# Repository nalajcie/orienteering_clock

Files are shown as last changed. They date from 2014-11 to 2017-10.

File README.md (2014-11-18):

# Introduction
This is *work-in-progress* project to build orienteering clock, currently in prototyping phase. I will put more information here when it will be completed.

# Contents
 * `src/` - Arduino prototype source for driving multiplexed LED display and time counting. It's best to link this folder to your Arduino projects folder:
  
  ```
    in Windows:
    > mklink /D c:\Users\$USER\Documents\Arduino\orienteering_clock c:\proj\orienteering_clock\src

    in Linux:
    $ ln -s src /home/$USER/sketchbook/orienteering_clock
  ```
 
 * `schematics/` - EAGLE and PDF schematics of prototype parts. It's best to link this folder to your Eagle library:

  ```
    in Windows:
    > mklink /D c:\Users\$USER\Documents\eagle\orienteering-clock C:\proj\orienteering_clock\schematics

    in Linux:
    $ ln -s schematics /home/$USER/eagle/orienteering-clock

  ```

 * `doc/` - documentation of parts, etc.

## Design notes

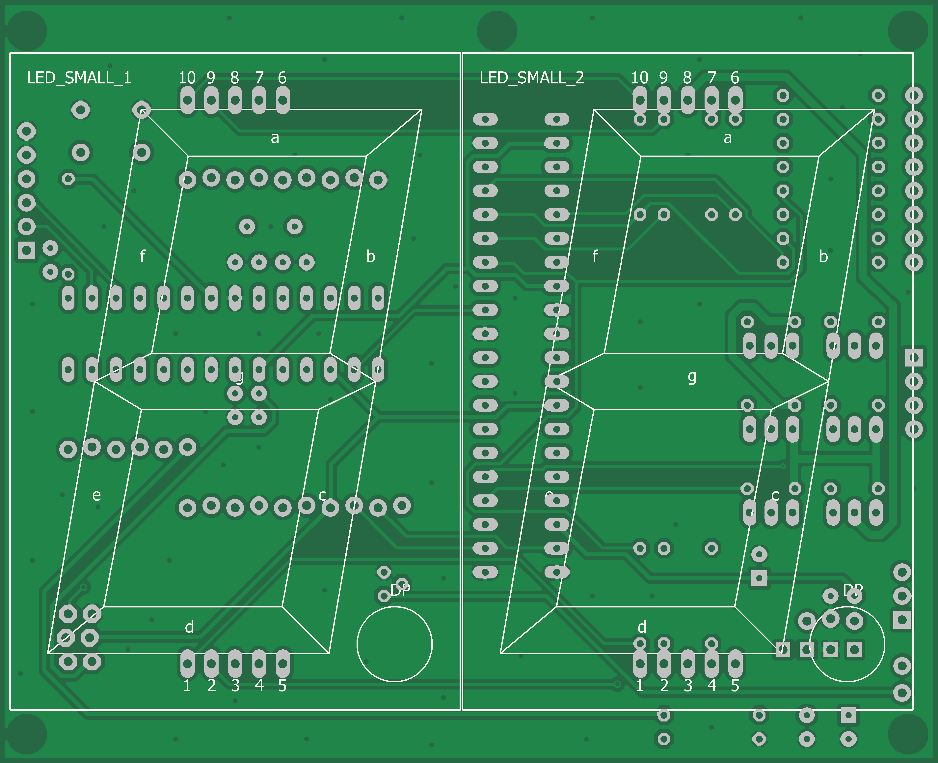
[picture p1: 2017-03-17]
schematics/eagleUp/eagleUp_orienteering_clock_rev2_board_bottom.png

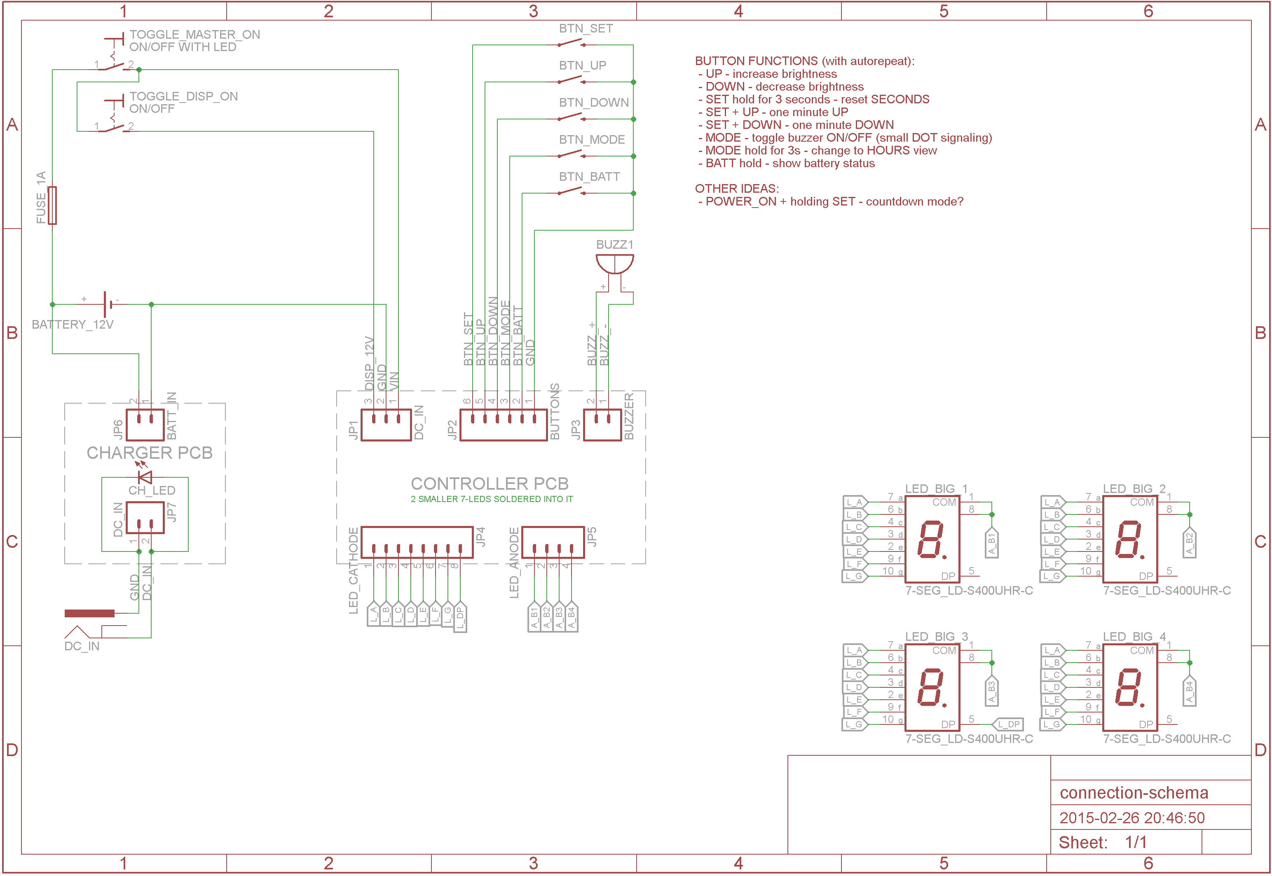
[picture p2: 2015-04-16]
schematics/pdf/connection-schema.sch.png

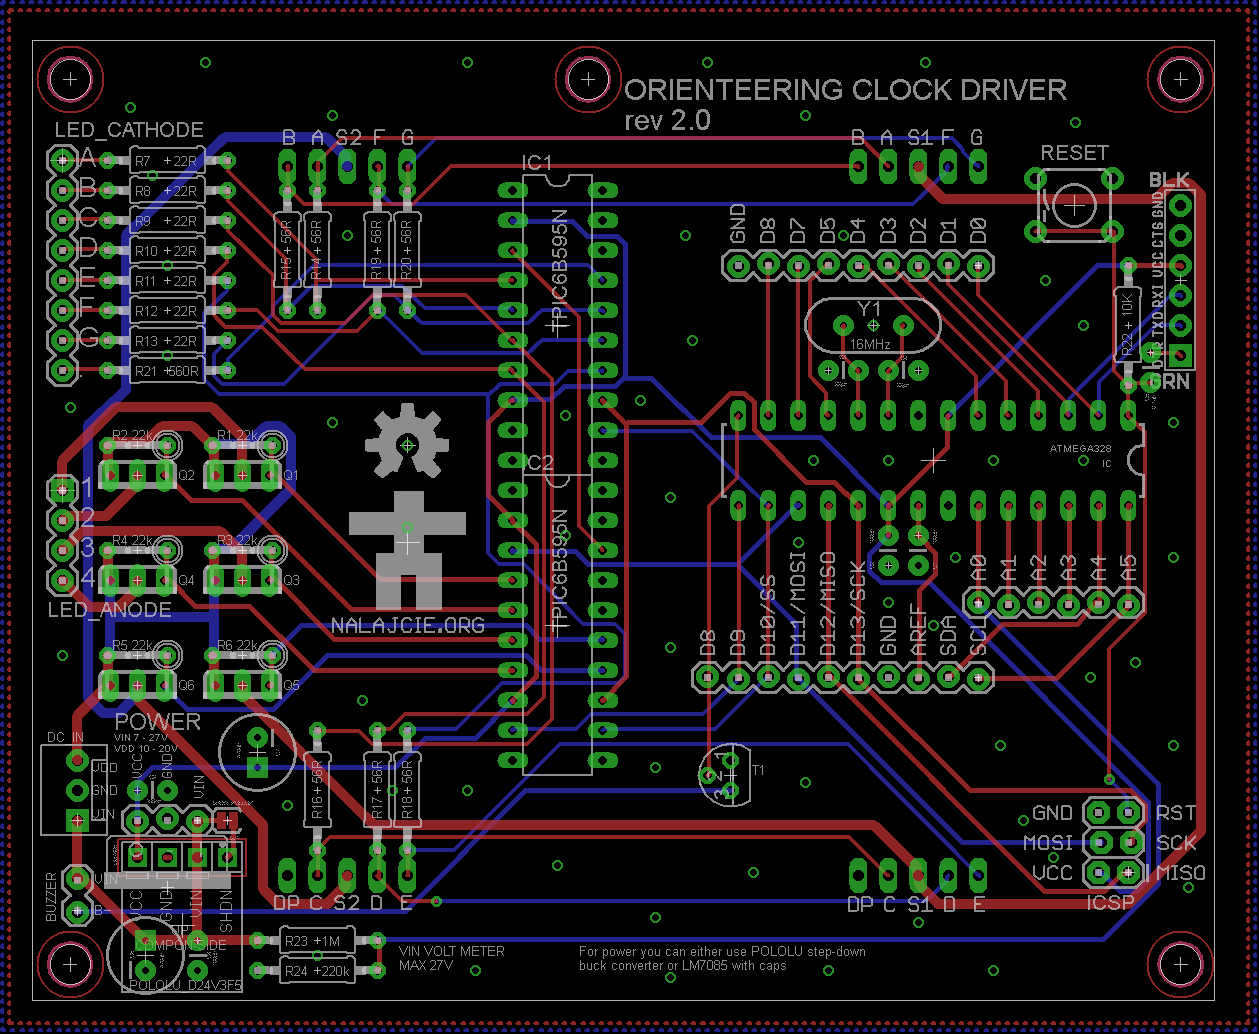
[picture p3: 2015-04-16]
schematics/pdf/orienteering_clock_rev2.brd.png

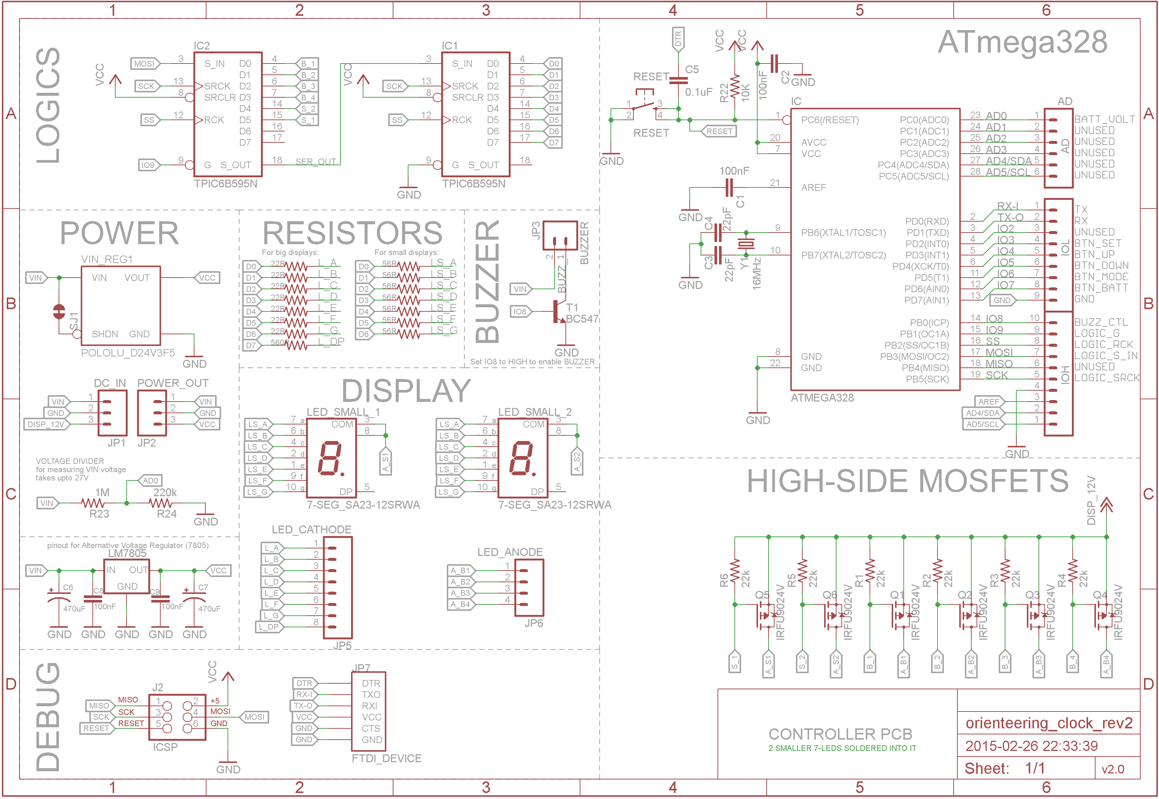
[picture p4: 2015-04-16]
schematics/pdf/orienteering_clock_rev2.sch.png

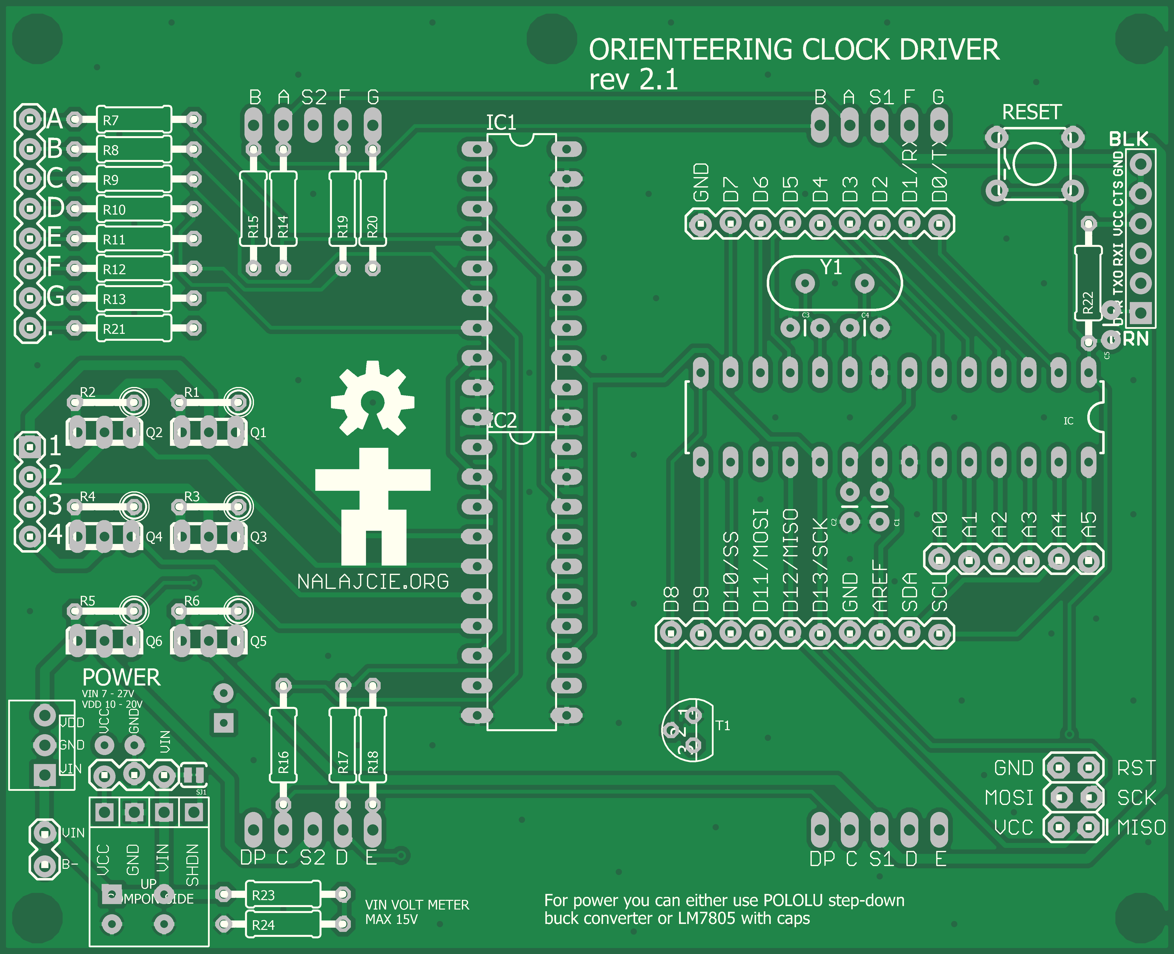
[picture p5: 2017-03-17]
schematics/eagleUp/eagleUp_orienteering_clock_rev2_board_top.png

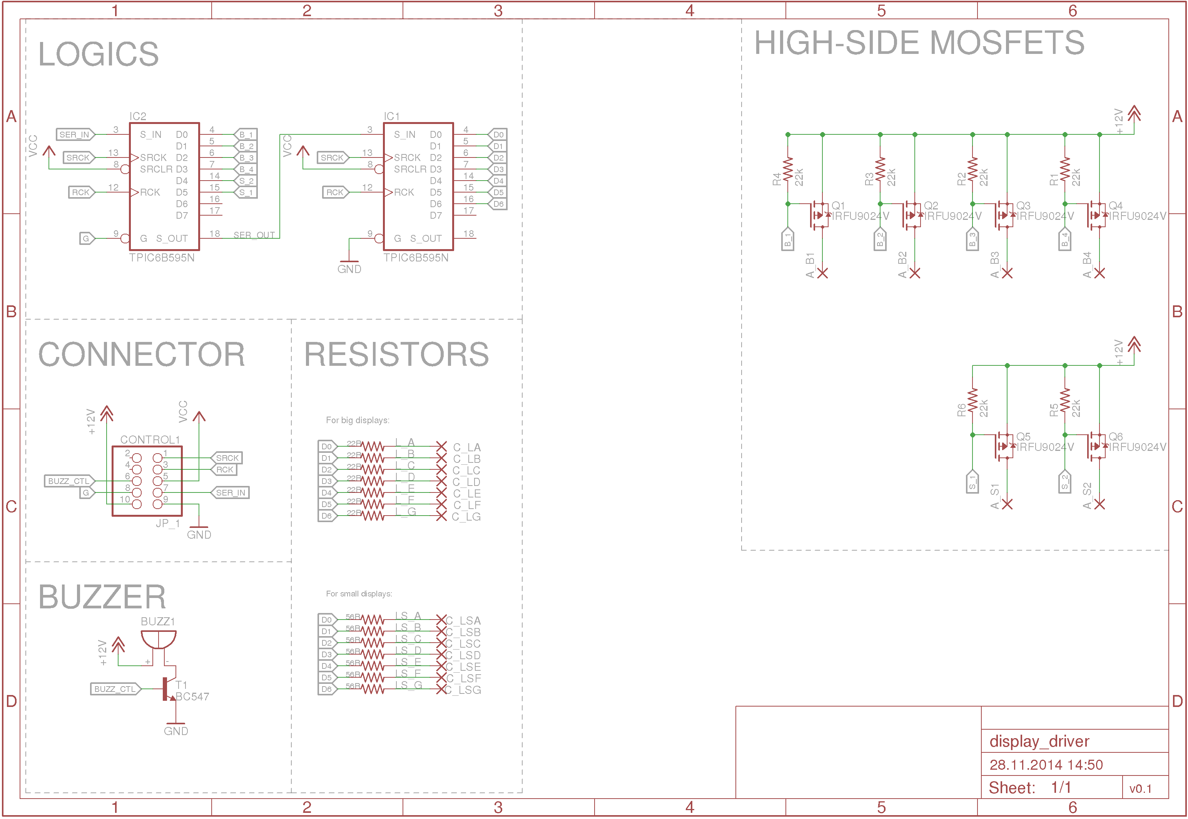
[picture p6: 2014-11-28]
schematics/v1.0/display_driver_schematics.png

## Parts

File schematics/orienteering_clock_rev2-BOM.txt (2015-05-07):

Partlist exported from C:/proj/orienteering_clock/schematics/orienteering_clock_rev2.sch at 2015-04-16 19:34:28

Part        Value             Device                   Package                           Description                                                          
AD          AD                M06SIP_LOCK              1X06-SIP_LOCK                     Header 6                                                             
C1          100nF             CAPPTH                   CAP-PTH-SMALL                     Capacitor                                                            
C2          100nF             CAPPTH                   CAP-PTH-SMALL                     Capacitor                                                            
C3          22pF              CAPPTH                   CAP-PTH-SMALL                     Capacitor                                                            
C4          22pF              CAPPTH                   CAP-PTH-SMALL                     Capacitor                                                            
C5          0.1uF             CAPPTH                   CAP-PTH-SMALL                     Capacitor                                                            
C6          470uF             CAP_POLPTH1              CPOL-RADIAL-100UF-25V             Capacitor Polarized                                                  
C7          470uF             CAP_POLPTH1              CPOL-RADIAL-100UF-25V             Capacitor Polarized                                                  
C8          100nF             CAPPTH                   CAP-PTH-SMALL                     Capacitor                                                            
C9          100nF             CAPPTH                   CAP-PTH-SMALL                     Capacitor                                                            
IC          ATMEGA328         ATMEGA328P_PDIP          DIL28-3                           uC used in the Arduino                                               
IC1         TPIC6B595N        TPIC6B595N               DIL20                             8-bit SHIFT REGISTER, output latch                                   
IC2         TPIC6B595N        TPIC6B595N               DIL20                             8-bit SHIFT REGISTER, output latch                                   
IOH         M10LOCK           M10LOCK                  1X10_LOCK                         Header 10                                                            
IOL         M09LOCK           M09LOCK                  1X09_LOCK                         Header 9                                                             
J2          ICSP              AVR_SPI_PRG_62X3_LOCK    2X3_LOCK                          AVR ISP 6 Pin                                                        
JP1         DC_IN             M03POLAR                 MOLEX-1X3                         Header 3                                                             
JP2         POWER_OUT         M03LOCK                  1X03_LOCK                         Header 3                                                             
JP3         BUZZER            M02LOCK                  1X02_LOCK                         Standard 2-pin 0.1" header. Use with                                 
JP5         LED_CATHODE       M08                      1X08_ROUND                        Header 8                                                             
JP6         LED_ANODE         M04PTH                   1X04                              Header 4                                                             
JP7         FTDI_DEVICE       FTDI_DEVICE              FTDI_DEVICE_SIDE                  Connector which mates to FTDI basic or FTDI cable.                   
LED_SMALL_1 7-SEG_SA23-12SRWA 7-SEG_SA23-12SRWA        SA23-12SRWA                       Kingbright 14.2mm (0.56 INCH) SINGLE DIGIT NUMERIC DUISPLAY          
LED_SMALL_2 7-SEG_SA23-12SRWA 7-SEG_SA23-12SRWA        SA23-12SRWA                       Kingbright 14.2mm (0.56 INCH) SINGLE DIGIT NUMERIC DUISPLAY          
LM7805                        78XXS                    78XXS                             VOLTAGE REGULATOR - NO DRILL                                         
Q1          IRFU9024V         IRFU9024V                TO251AA-V                         P-CHANNEL MOSFET                                                     
Q2          IRFU9024V         IRFU9024V                TO251AA-V                         P-CHANNEL MOSFET                                                     
Q3          IRFU9024V         IRFU9024V                TO251AA-V                         P-CHANNEL MOSFET                                                     
Q4          IRFU9024V         IRFU9024V                TO251AA-V                         P-CHANNEL MOSFET                                                     
Q5          IRFU9024V         IRFU9024V                TO251AA-V                         P-CHANNEL MOSFET                                                     
Q6          IRFU9024V         IRFU9024V                TO251AA-V                         P-CHANNEL MOSFET                                                     
R1          22k               R-US_0207/5V             0207/5V                           RESISTOR, American symbol                                            
R2          22k               R-US_0207/5V             0207/5V                           RESISTOR, American symbol                                            
R3          22k               R-US_0207/5V             0207/5V                           RESISTOR, American symbol                                            
R4          22k               R-US_0207/5V             0207/5V                           RESISTOR, American symbol                                            
R5          22k               R-US_0207/5V             0207/5V                           RESISTOR, American symbol                                            
R6          22k               R-US_0207/5V             0207/5V                           RESISTOR, American symbol                                            
R7          22R               R-US_0207/10             0207/10                           RESISTOR, American symbol                                            
R8          22R               R-US_0207/10             0207/10                           RESISTOR, American symbol                                            
R9          22R               R-US_0207/10             0207/10                           RESISTOR, American symbol                                            
R10         22R               R-US_0207/10             0207/10                           RESISTOR, American symbol                                            
R11         22R               R-US_0207/10             0207/10                           RESISTOR, American symbol                                            
R12         22R               R-US_0207/10             0207/10                           RESISTOR, American symbol                                            
R13         22R               R-US_0207/10             0207/10                           RESISTOR, American symbol                                            
R14         56R               R-US_0207/10             0207/10                           RESISTOR, American symbol                                            
R15         56R               R-US_0207/10             0207/10                           RESISTOR, American symbol                                            
R16         56R               R-US_0207/10             0207/10                           RESISTOR, American symbol                                            
R17         56R               R-US_0207/10             0207/10                           RESISTOR, American symbol                                            
R18         56R               R-US_0207/10             0207/10                           RESISTOR, American symbol                                            
R19         56R               R-US_0207/10             0207/10                           RESISTOR, American symbol                                            
R20         56R               R-US_0207/10             0207/10                           RESISTOR, American symbol                                            
R21         560R              R-US_0207/10             0207/10                           RESISTOR, American symbol                                            
R22         10K               R-US_0207/10             0207/10                           RESISTOR, American symbol                                            
R23         1M                R-US_0207/10             0207/10                           RESISTOR, American symbol                                            
R24         220k              R-US_0207/10             0207/10                           RESISTOR, American symbol                                            
RESET       RESET             TAC_SWITCHPTH            TACTILE-PTH                       Momentary Switch                                                     
SJ1         SHDN_PULLUP       JUMPER-PAD-2-NC_BY_TRACE PAD-JUMPER-2-NC_BY_TRACE_YES_SILK                                                                      
T1          BC547             BC547                    TO92                              NPN TRANSISTOR                                                       
VIN_REG1    POLOLU_D24V3F5    POLOLU_D24V3F5-HC        POLOLU_D24V3F_HC                  Pololu Step Down Voltage Regulators Series D24V3F_ (300 mA)0.4"x0.5" 
Y1          16MHz             CRYSTALHC49US            HC49US                            Various standard crystals. Proven footprints.

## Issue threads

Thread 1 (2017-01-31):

Use old mobile display (resources)

Symbian9, 2017-01-31:
Here some usefull resources for using old mobile displays with Arduino:
* http://andybrown.me.uk/downloads/
  * https://github.com/andysworkshop/xmemtft

nalajcie, 2017-01-31:
We don't want to use old mobile displays for this kind of clock (they are waaay too small).

Currently we're using quite large 7-segment led display (single digit is 90x120mm).

I'll try to post more detailed instructions regarding build in the future, for now the finished clock looks like that:
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

Closed 2017-01-31.

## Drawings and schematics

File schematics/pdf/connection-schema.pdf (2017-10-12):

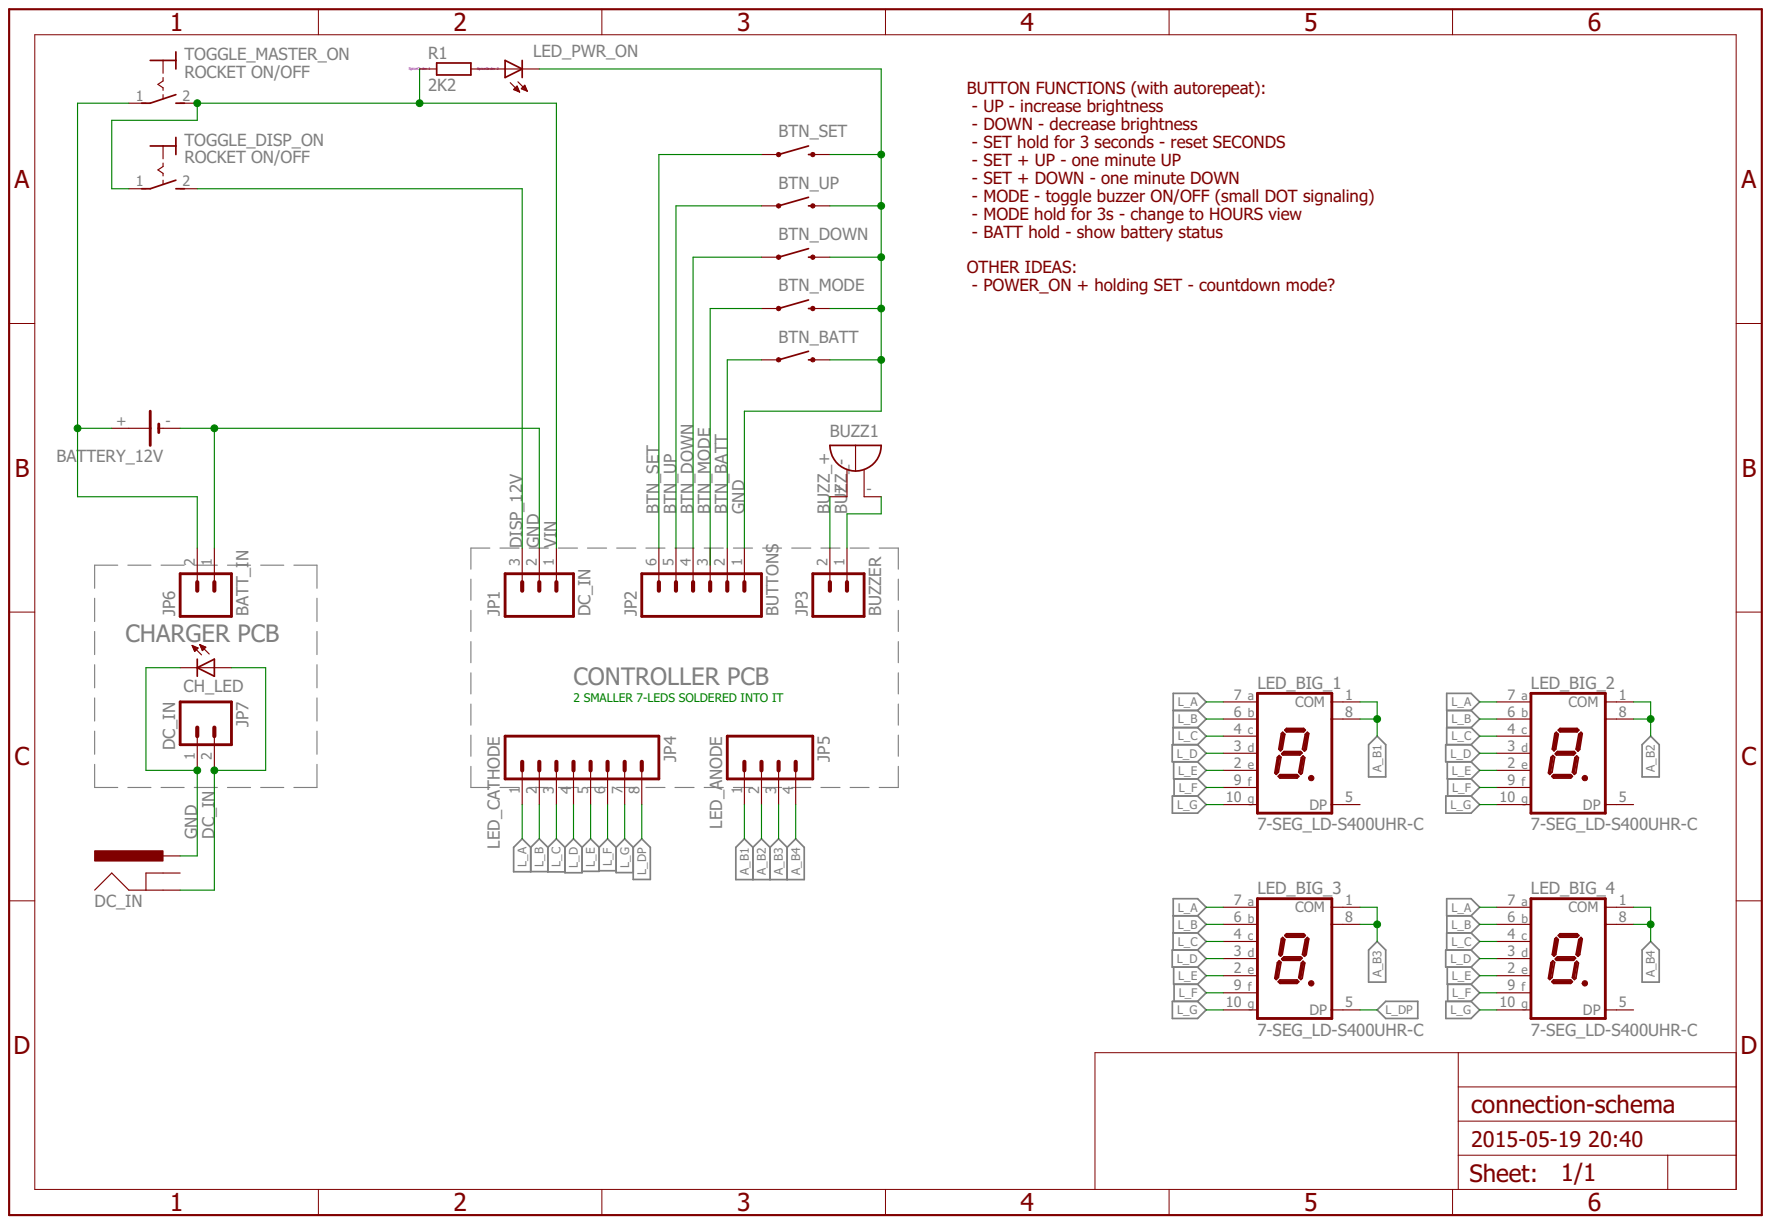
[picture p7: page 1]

BUTTON FUNCTIONS (with autorepeat): - UP - increase brightness

- DOWN - decrease brightness
- SET hold for 3 seconds - reset SECONDS
- SET + UP - one minute UP
- SET + DOWN - one minute DOWN
- MODE - toggle buzzer ON/OFF (small DOT signaling)
- MODE hold for 3s - change to HOURS view
- BATT hold - show battery status OTHER IDEAS: - POWER_ON + holding SET - countdown mode?

2 SMALLER 7-LEDS SOLDERED INTO IT

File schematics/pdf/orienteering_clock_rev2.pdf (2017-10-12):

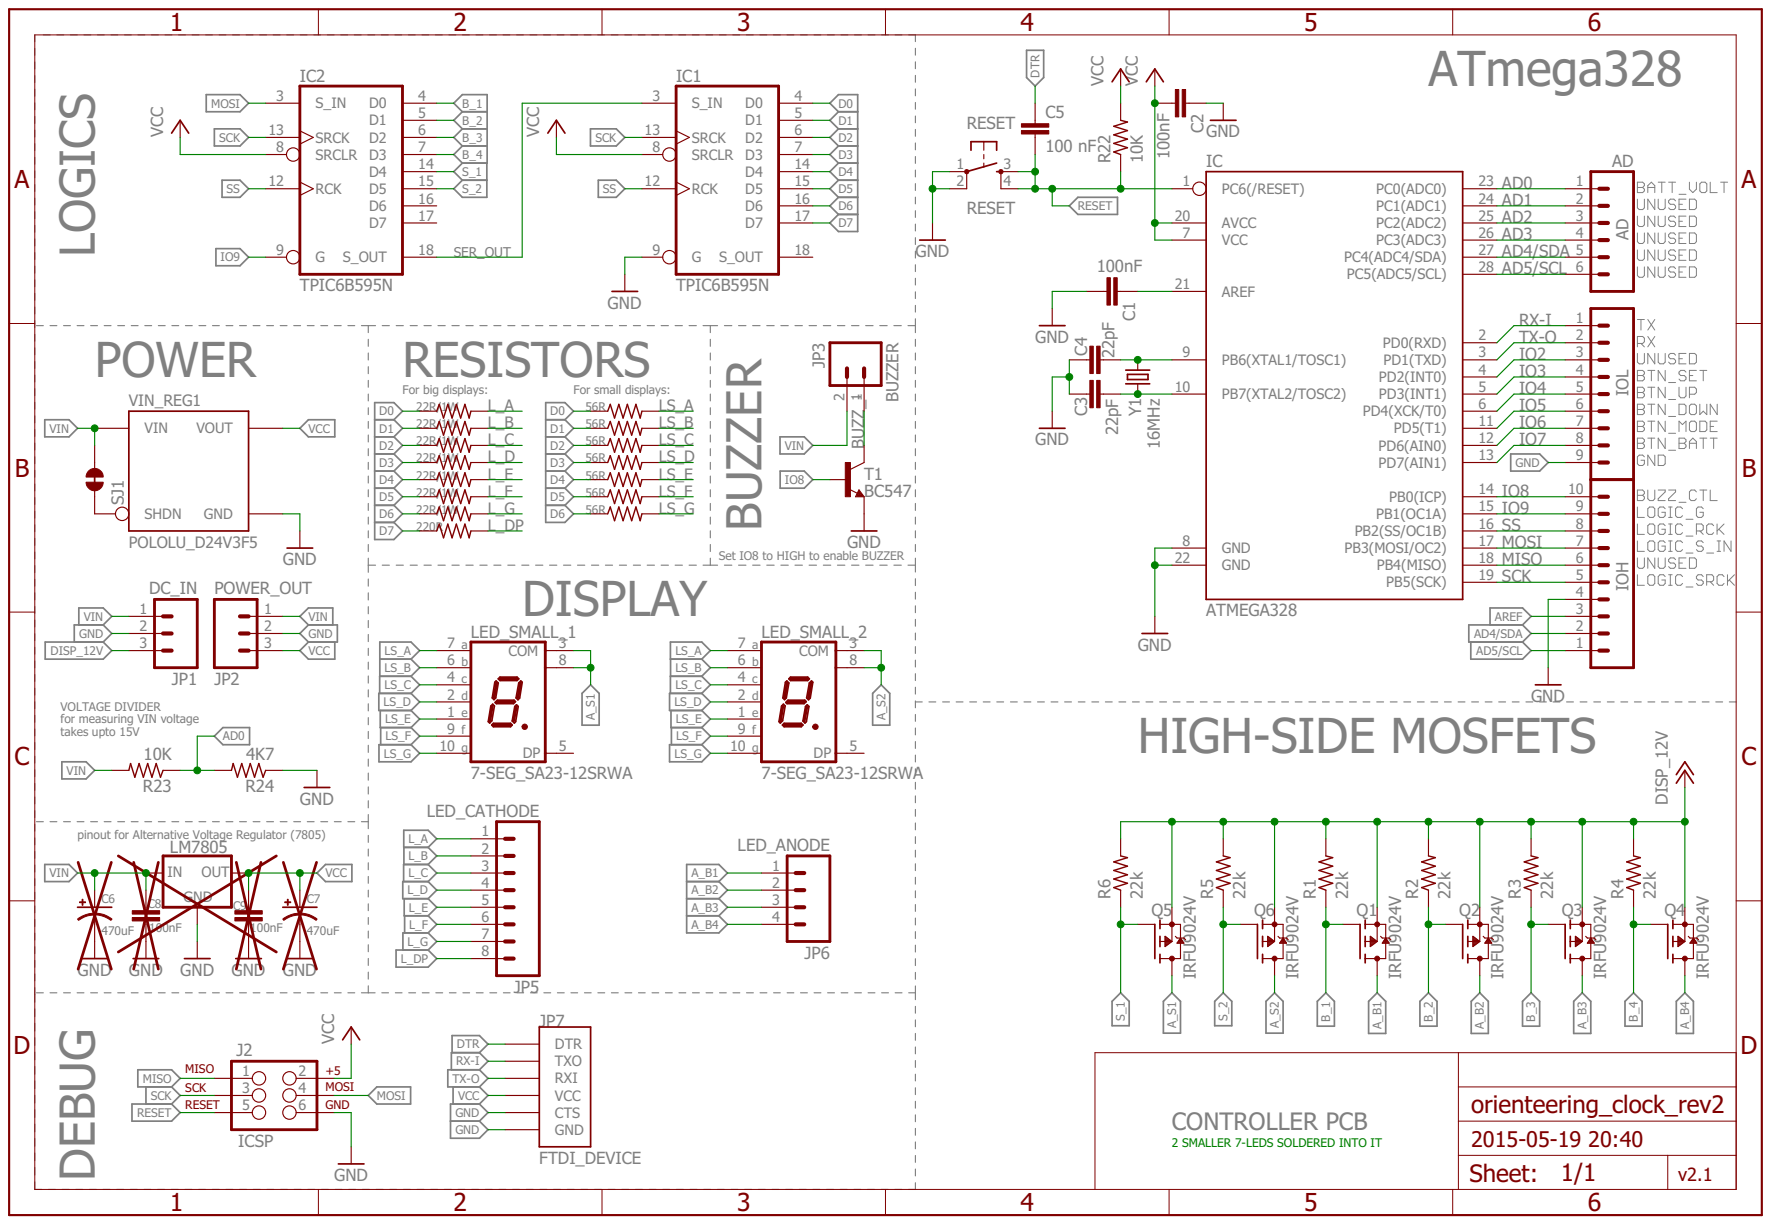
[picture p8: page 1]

Set IO8 to HIGH to enable BUZZER

VOLTAGE DIVIDER
for measuring VIN voltage
takes upto 15V

pinout for Alternative Voltage Regulator (7805)

2 SMALLER 7-LEDS SOLDERED INTO IT

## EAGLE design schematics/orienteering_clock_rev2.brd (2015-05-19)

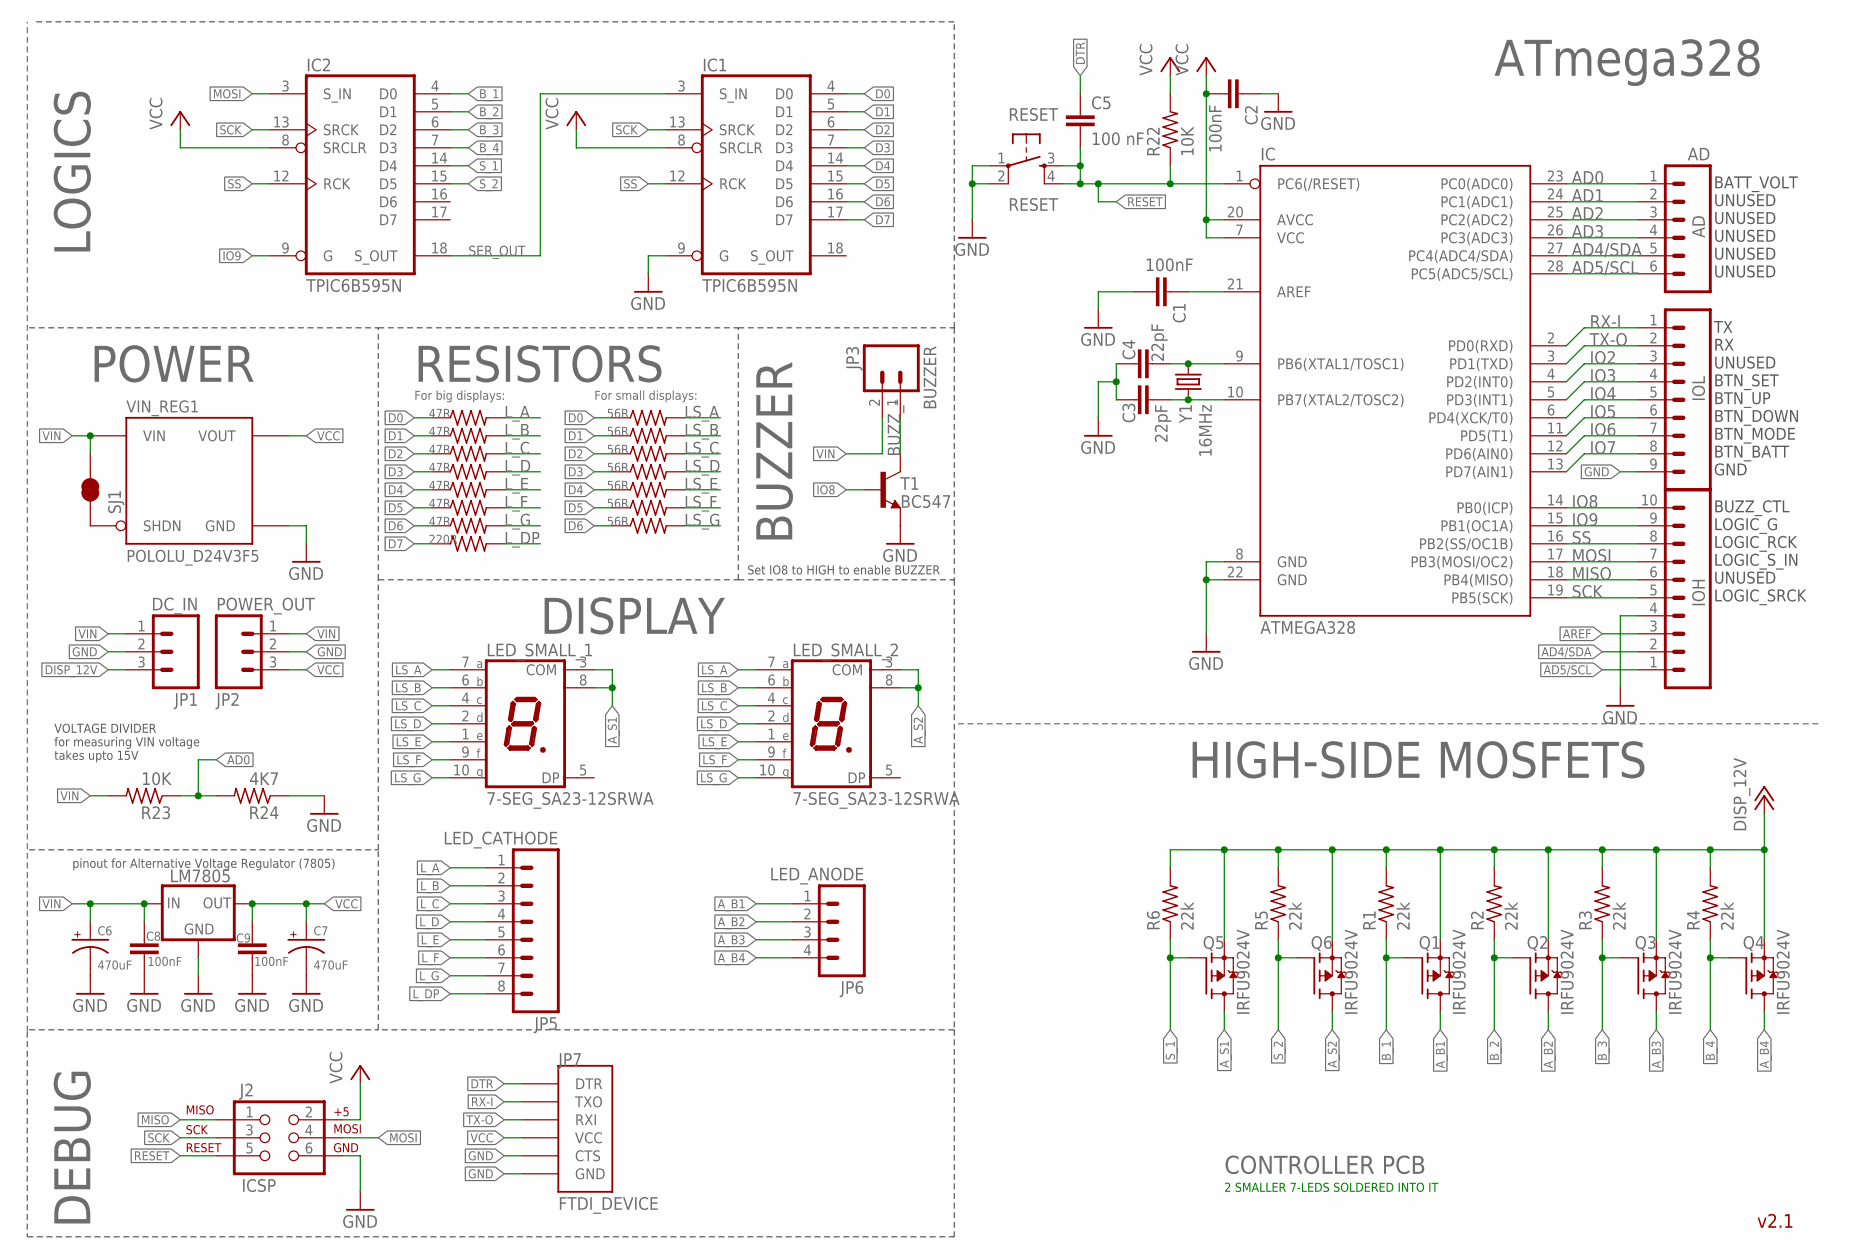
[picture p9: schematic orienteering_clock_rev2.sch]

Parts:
AD: AD; 1X06-SIP_LOCK
C1, C2, C8, C9: 100nF; CAP-PTH-SMALL
C3, C4: 22pF; CAP-PTH-SMALL
C5: 100 nF; CAP-PTH-SMALL
C6, C7: 470uF; CPOL-RADIAL-100UF-25V
IC: ATMEGA328; DIL28-3
IC1, IC2: TPIC6B595N; DIL20
IOH: M10LOCK; 1X10_LOCK
IOL: M09LOCK; 1X09_LOCK
J2: ICSP; 2X3_LOCK
JP1: DC_IN; MOLEX-1X3
JP2: POWER_OUT; 1X03_LOCK
JP3: BUZZER; 1X02_LOCK
JP5: LED_CATHODE; 1X08_ROUND
JP6: LED_ANODE; 1X04
JP7: FTDI_DEVICE; FTDI_DEVICE_SIDE
LED_SMALL_1, LED_SMALL_2: 7-SEG_SA23-12SRWA; SA23-12SRWA
LM7805: 78XXS
Q1, Q2, Q3, Q4, Q5, Q6: IRFU9024V; TO251AA-V
R1, R2, R3, R4, R5, R6: 22k; 0207/5V
R7, R8, R9, R10, R11, R12, R13: 47R; 0207/10
R14, R15, R16, R17, R18, R19, R20: 56R; 0207/10
R21: 220R; 0207/10
R22, R23: 10K; 0207/10
R24: 4K7; 0207/10
RESET: RESET; TACTILE-PTH
SJ1: SHDN_PULLUP; PAD-JUMPER-2-NC_BY_TRACE_YES_SILK
T1: BC547; TO92
VIN_REG1: POLOLU_D24V3F5; POLOLU_D24V3F_HC
Y1: 16MHz; HC49US

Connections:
AD0: AD.1, IC.23 (PC0(ADC0)), R23.1, R24.2
AD1: AD.2, IC.24 (PC1(ADC1))
AD2: AD.3, IC.25 (PC2(ADC2))
AD3: AD.4, IC.26 (PC3(ADC3))
AD4/SDA: AD.5, IC.27 (PC4(ADC4/SDA)), IOH.2
AD5/SCL: AD.6, IC.28 (PC5(ADC5/SCL)), IOH.1
AREF: C1.1, IC.21 (AREF), IOH.3
A_B1: JP6.1, Q1.2 (D)
A_B2: JP6.2, Q2.2 (D)
A_B3: JP6.3, Q3.2 (D)
A_B4: JP6.4, Q4.2 (D)
A_S1: LED_SMALL_1.3 (COM), LED_SMALL_1.8 (COM), Q5.2 (D)
A_S2: LED_SMALL_2.3 (COM), LED_SMALL_2.8 (COM), Q6.2 (D)
BUZZ_-: JP3.1, T1.3 (C)
B_1: IC2.4 (D0), Q1.1 (G), R1.1
B_2: IC2.5 (D1), Q2.1 (G), R2.1
B_3: IC2.6 (D2), Q3.1 (G), R3.1
B_4: IC2.7 (D3), Q4.1 (G), R4.1
D0: IC1.4 (D0), R7.1, R14.1
D1: IC1.5 (D1), R8.1, R15.1
D2: IC1.6 (D2), R9.1, R16.1
D3: IC1.7 (D3), R10.1, R17.1
D4: IC1.14 (D4), R11.1, R18.1
D5: IC1.15 (D5), R12.1, R19.1
D6: IC1.16 (D6), R13.1, R20.1
D7: IC1.17 (D7), R21.1
DISP_12V: JP1.3, Q1.3 (S), Q2.3 (S), Q3.3 (S), Q4.3 (S), Q5.3 (S), Q6.3 (S), R1.2, R2.2, R3.2, R4.2, R5.2, R6.2
DTR: C5.1, JP7.P$1 (DTR)
GND: C1.2, C2.1, C3.1, C4.1, C6.2 (-), C7.2 (-), C8.2, C9.2, IC.8 (GND), IC.22 (GND), IC1.9 (G), IC1.10 (GND), IC1.11 (GND), IC1.19 (GND), IC2.10 (GND), IC2.11 (GND), IC2.19 (GND), IOH.4, IOL.9, J2.6, JP1.2, JP2.2, JP7.P$5 (CTS), JP7.P$6 (GND), LM7805.GND, R24.1, RESET.1, RESET.2, T1.1 (E), VIN_REG1.G (GND)
IO2: IC.4 (PD2(INT0)), IOL.3
IO3: IC.5 (PD3(INT1)), IOL.4
IO4: IC.6 (PD4(XCK/T0)), IOL.5
IO5: IC.11 (PD5(T1)), IOL.6
IO6: IC.12 (PD6(AIN0)), IOL.7
IO7: IC.13 (PD7(AIN1)), IOL.8
IO8: IC.14 (PB0(ICP)), IOH.10, T1.2 (B)
IO9: IC.15 (PB1(OC1A)), IC2.9 (G), IOH.9
LS_A: LED_SMALL_1.7 (A), LED_SMALL_2.7 (A), R14.2
LS_B: LED_SMALL_1.6 (B), LED_SMALL_2.6 (B), R15.2
LS_C: LED_SMALL_1.4 (C), LED_SMALL_2.4 (C), R16.2
LS_D: LED_SMALL_1.2 (D), LED_SMALL_2.2 (D), R17.2
LS_E: LED_SMALL_1.1 (E), LED_SMALL_2.1 (E), R18.2
LS_F: LED_SMALL_1.9 (F), LED_SMALL_2.9 (F), R19.2
LS_G: LED_SMALL_1.10 (G), LED_SMALL_2.10 (G), R20.2
L_A: JP5.1, R7.2
L_B: JP5.2, R8.2
L_C: JP5.3, R9.2
L_D: JP5.4, R10.2
L_DP: JP5.8, R21.2
L_E: JP5.5, R11.2
L_F: JP5.6, R12.2
L_G: JP5.7, R13.2
MISO: IC.18 (PB4(MISO)), IOH.6, J2.1
MOSI: IC.17 (PB3(MOSI/OC2)), IC2.3 (S_IN), IOH.7, J2.4
unnamed: SJ1.2, VIN_REG1.S (SHDN)
unnamed: C4.2, IC.9 (PB6(XTAL1/TOSC1)), Y1.2
unnamed: C3.2, IC.10 (PB7(XTAL2/TOSC2)), Y1.1
RESET: C5.2, IC.1 (PC6(/RESET)), J2.5, R22.1, RESET.3, RESET.4
RX-I: IC.2 (PD0(RXD)), IOL.1, JP7.P$2 (TXO)
SCK: IC.19 (PB5(SCK)), IC1.13 (SRCK), IC2.13 (SRCK), IOH.5, J2.3
SER_OUT: IC1.3 (S_IN), IC2.18 (S_OUT)
SS: IC.16 (PB2(SS/OC1B)), IC1.12 (RCK), IC2.12 (RCK), IOH.8
S_1: IC2.14 (D4), Q5.1 (G), R6.1
S_2: IC2.15 (D5), Q6.1 (G), R5.1
TX-O: IC.3 (PD1(TXD)), IOL.2, JP7.P$3 (RXI)
VCC: C2.2, C7.1 (+), C9.1, IC.7 (VCC), IC.20 (AVCC), IC1.2 (VCC), IC1.8 (SRCLR), IC2.2 (VCC), IC2.8 (SRCLR), J2.2, JP2.3, JP7.P$4 (VCC), LM7805.OUT, R22.2, VIN_REG1.O (VOUT)
VIN: C6.1 (+), C8.1, JP1.1, JP2.1, JP3.2, LM7805.IN, R23.2, SJ1.1, VIN_REG1.I (VIN)

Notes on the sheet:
RESISTORS
LOGICS
HIGH-SIDE MOSFETS
DEBUG
For big displays:
For small displays:
ATmega328
CONTROLLER PCB
2 SMALLER 7-LEDS SOLDERED INTO IT
DISPLAY
BUZZER
POWER
VOLTAGE DIVIDER for measuring VIN voltage takes upto 15V
Set IO8 to HIGH to enable BUZZER
TX RX UNUSED BTN_SET BTN_UP BTN_DOWN BTN_MODE BTN_BATT GND
BUZZ_CTL LOGIC_G LOGIC_RCK LOGIC_S_IN UNUSED LOGIC_SRCK
BATT_VOLT UNUSED UNUSED UNUSED UNUSED UNUSED
pinout for Alternative Voltage Regulator (7805)

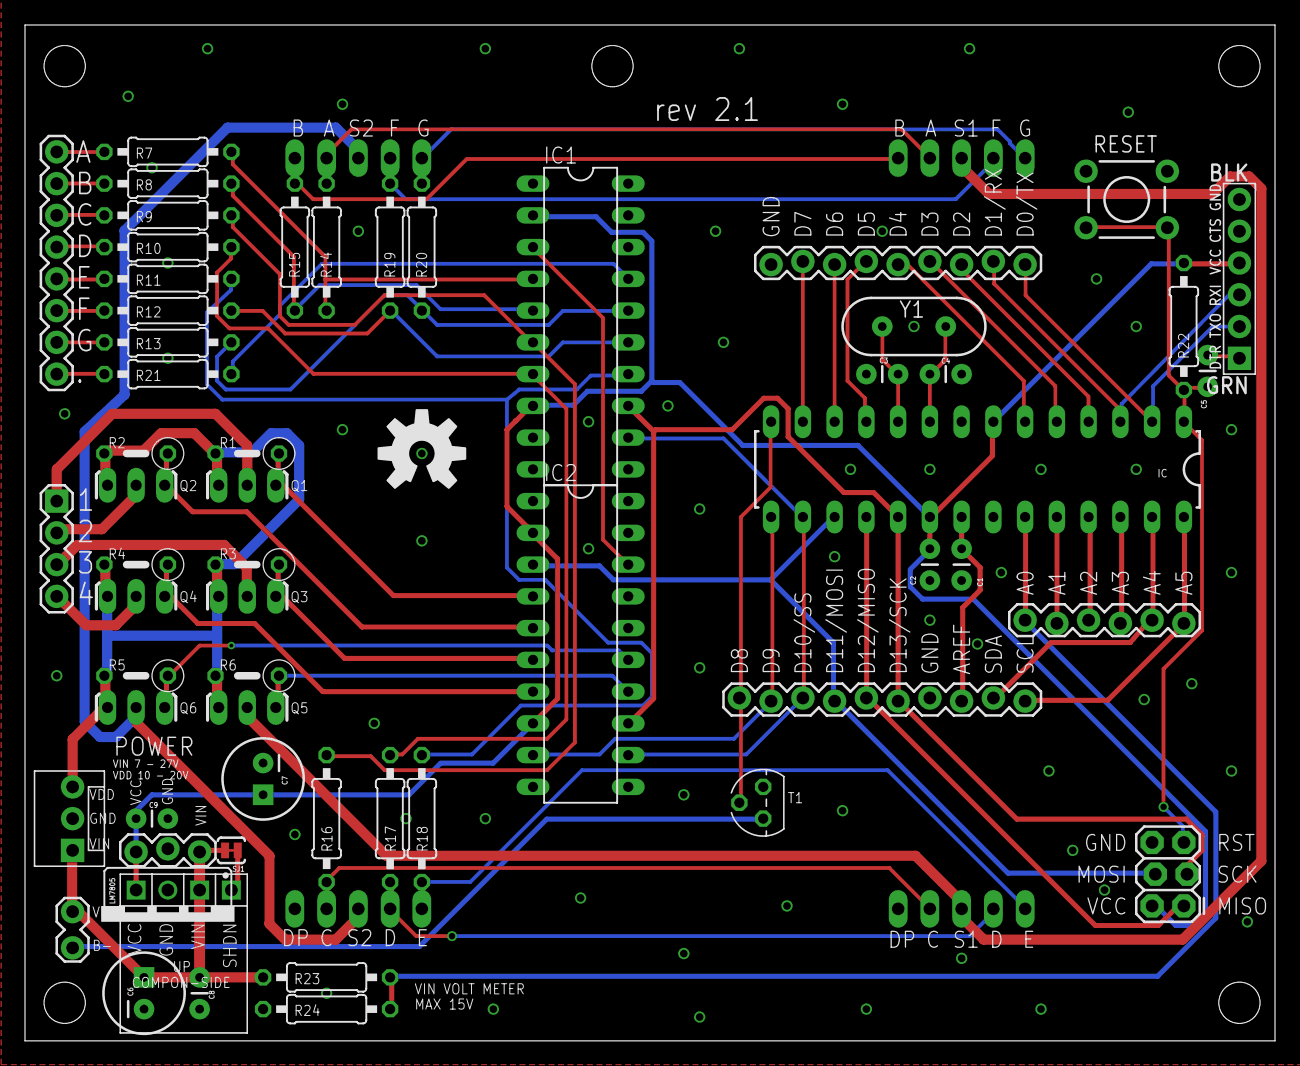
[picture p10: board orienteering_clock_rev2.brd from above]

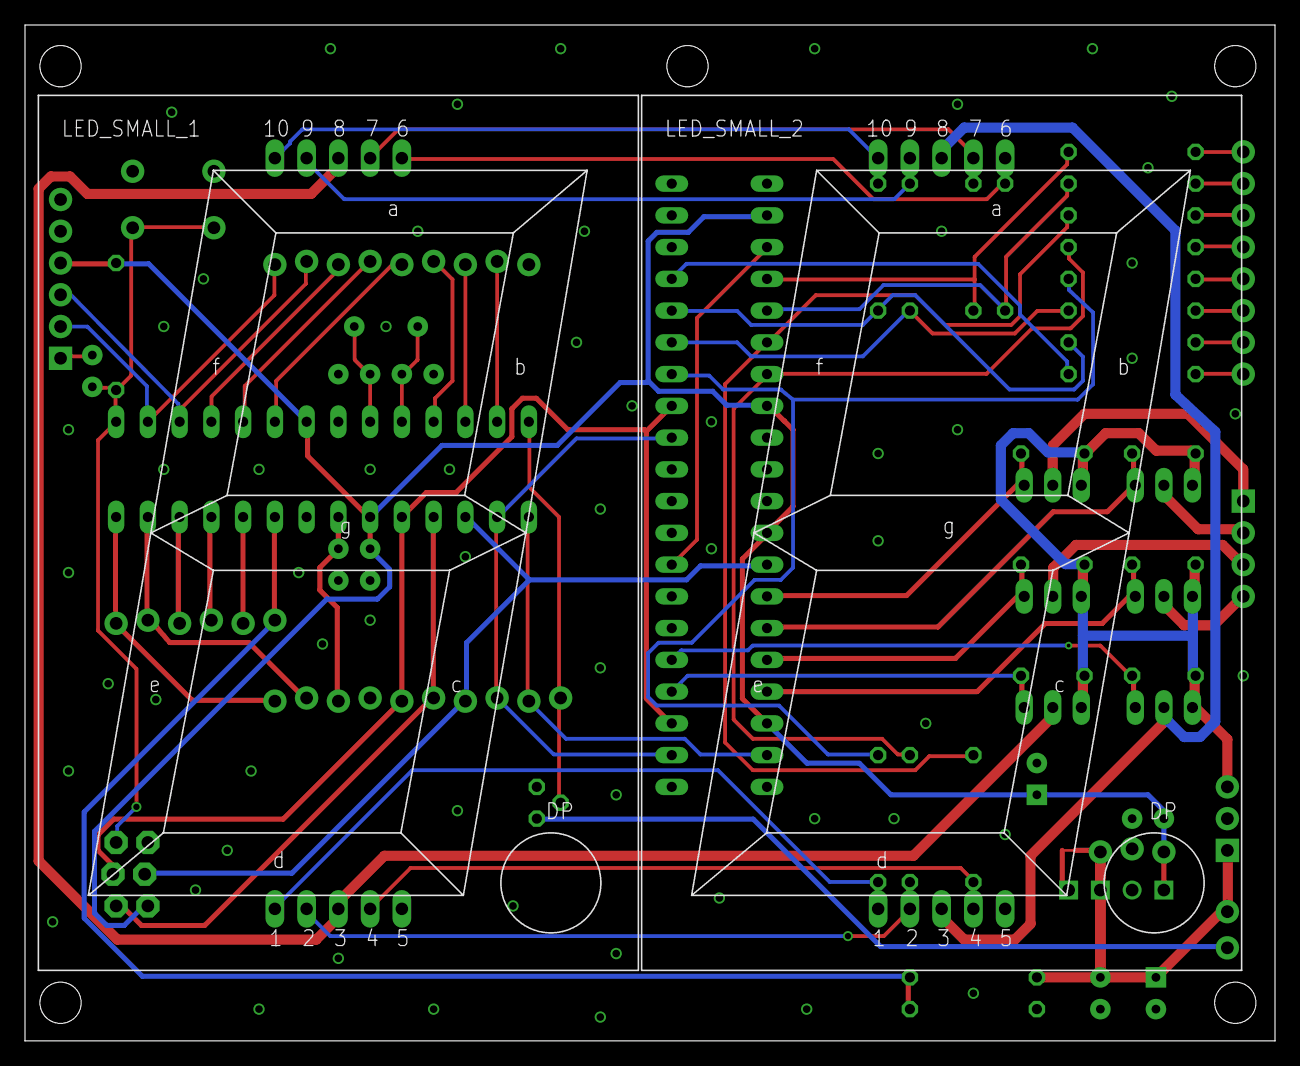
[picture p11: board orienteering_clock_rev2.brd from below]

Board: 2 copper layers, 100.0 x 81.3 mm, 67 parts (2 on the bottom side), 67 nets.

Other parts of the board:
E$1: OSHW-LOGO-L
E$2: DARWINIA-LOGO
JP4, JP8, JP9, JP10, JP11: STAND-OFF

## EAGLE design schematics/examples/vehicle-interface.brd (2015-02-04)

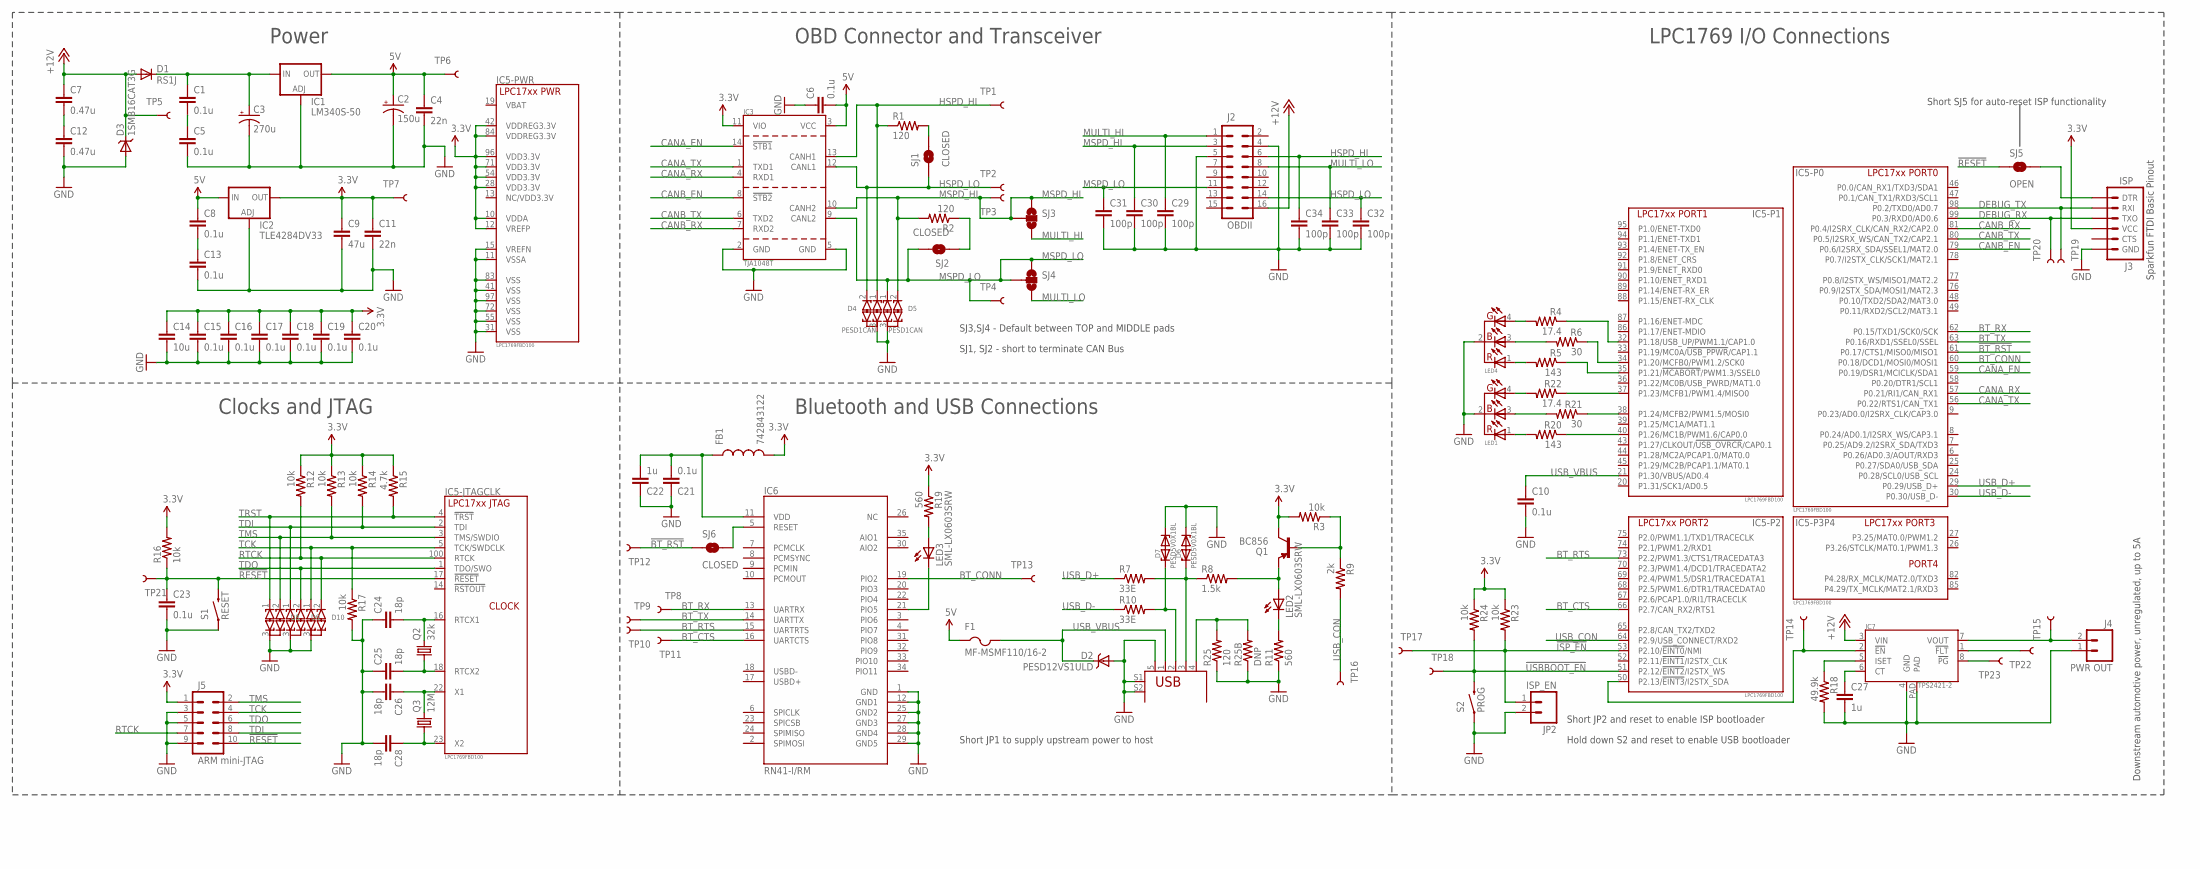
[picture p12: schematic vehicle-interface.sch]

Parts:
C1, C5, C8, C13: 0.1u; 0805
C2: 150u; CPOL-5MMX2D
C3: 270u; CPOL-10MMX5D
C4, C11: 22n; 0402-CAP
C6, C10, C15, C16, C17, C18, C19, C20, C21, C23: 0.1u; 0402-CAP
C7, C12: 0.47u; 0805
C9: 47u; 1210
C14: 10u; 0805
C22, C27: 1u; 0402-CAP
C24, C25, C26, C28: 18p; 0402-CAP
C29, C30, C31, C32, C33, C34: 100p; 0402-CAP
D1: RS1J; SMA-DIODE
D2: PESD12VS1ULD; SOD-882D
D3: 1SMB16CAT3G; SMB-DIODE
D4, D5: PESD1CAN; SOT23
D6, D7: PESD5V0X1BL; SOD-882
D8, D9, D10: DIODE_ESD_DUAL-SOT-1123; SOT-1123
F1: MF-MSMF110/16-2; R1206
FB1: 742843122; C0402
IC1: LM340S-50; V-REG_DPACK
IC2: TLE4284DV33; V-REG_DPACK
IC3: TJA1048T; SO14
IC5: LPC1769FBD100; TQFP100
IC6: RN41-I/RM; RN41
IC7: TPS2421-2; POWER_SO8
J1: USB_MINIB_SHIELD-10118193; 10118193
J2: OBDII; OBDII-COMTECH
J3: ISP; 1X06
J4: PWR OUT; 2-1445055-2
J5: ARM mini-JTAG; SHF-105-01-X-D-SM
JP2: ISP_EN; 1X02
LED1, LED4: RGB; LED5MM-RGB
LED2, LED3: SML-LX0603SRW; LED-0603
Q1: BC856; SOT23-3
Q2: 32k; ST2012SB
Q3: 12M; CX3225SB
R1, R2, R25: 120; 0402-RES
R3, R12, R13, R14, R16, R17, R23, R24: 10k; 0402-RES
R4, R22: 17.4; 0402-RES
R5, R20: 143; 0402-RES
R6, R21: 30; 0402-RES
R7, R10: 33E; 0402-RES
R8: 1.5k; 0402-RES
R9: 2k; 0402-RES
R11, R19: 560; 0402-RES
R15: 4.7k; 0402-RES
R18: 49.9k; 0402-RES
R25B: DNP; AXIAL-0.4
S1: RESET; TACTILE-SWITCH-1101NE
S2: PROG; TACTILE-SWITCH-1101NE
SJ1, SJ2, SJ6: CLOSED; SJ_2S-TRACE
SJ3, SJ4: SOLDERJUMPER_2WAYPASTE1&2; SJ_3_PASTE1&2
SJ5: OPEN; SJ_2S-NO
TP1, TP2, TP3, TP4, TP5, TP6, TP7, TP8, TP9, TP10, TP11, TP12, TP13, TP14, TP15, TP16, TP17, TP18, TP19, TP20, TP21, TP22, TP23: TEST-POINT3X5; PAD.03X.05

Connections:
3.3V: C9.1, C11.1, C14.1, C15.1, C16.1, C17.1, C18.1, C19.1, C20.1, FB1.2, IC2.4 (OUT), IC3.11 (VIO), IC5.10 (VDDA), IC5.12 (VREFP), IC5.28 (VDD3.3V), IC5.42 (VDDREG3.3V), IC5.54 (VDD3.3V), IC5.71 (VDD3.3V), IC5.84 (VDDREG3.3V), IC5.96 (VDD3.3V), J3.4 (VCC), J5.1, Q1.3 (C), R3.2, R12.1, R13.1, R14.1, R15.1, R16.2, R19.1, R23.1, R24.1, TP7.P$1
5V: C2.1 (+), C4.1, C6.2, C8.1, F1.1, IC1.4 (OUT), IC2.3 (IN), IC3.3 (VCC), TP6.P$1
!BT_RST: IC5.61 (P0.17/CTS1/MISO0/MISO1), SJ6.1, TP12.P$1
!ISP_EN: IC5.53 (P2.10/!EINT0!/NMI), JP2.1, R23.2, TP17.P$1
!RESET: C23.1, IC5.17 (!RESET), J5.10, R16.1, S1.P$2 (2), SJ5.1, TP21.P$1
!USBBOOT_EN: IC5.51 (P2.12/!EINT2!/I2STX_WS), R24.2, S2.P$2 (2), TP18.P$1
+12V: C7.1, D1.A, D3.C, IC7.3 (VIN), J2.16, TP5.P$1
BT_CONN: IC5.60 (P0.18/DCD1/MOSI0/MOSI1), IC6.19 (PIO2), TP13.P$1
BT_CTS: IC5.66 (P2.7/CAN_RX2/RTS1), IC6.16 (UARTCTS), TP11.P$1
BT_RTS: IC5.73 (P2.2/PWM1.3/CTS1/TRACEDATA3), IC6.15 (UARTRTS), TP10.P$1
BT_RX: IC5.62 (P0.15/TXD1/SCK0/SCK), IC6.13 (UARTRX), TP8.P$1
BT_TX: IC5.63 (P0.16/RXD1/SSEL0/SSEL), IC6.14 (UARTTX), TP9.P$1
CANA_EN: IC3.14 (!STB1), IC5.59 (P0.19/DSR1/MCICLK/SDA1)
CANA_RX: IC3.4 (RXD1), IC5.57 (P0.21/RI1/CAN_RX1)
CANA_TX: IC3.1 (TXD1), IC5.56 (P0.22/RTS1/CAN_TX1)
CANB_EN: IC3.8 (!STB2), IC5.79 (P0.6/I2SRX_SDA/SSEL1/MAT2.0)
CANB_RX: IC3.7 (RXD2), IC5.81 (P0.4/I2SRX_CLK/CAN_RX2/CAP2.0)
CANB_TX: IC3.6 (TXD2), IC5.80 (P0.5/I2SRX_WS/CAN_TX2/CAP2.1)
DEBUG_RX: IC5.99 (P0.3/RXD0/AD0.6), J3.3 (TXO), TP20.P$1
DEBUG_TX: IC5.98 (P0.2/TXD0/AD0.7), J3.2 (RXI), TP19.P$1
GND: C2.2 (-), C3.1 (-), C4.2, C5.2, C6.1, C9.2, C10.2, C11.2, C12.2, C13.2, C14.2, C15.2, C16.2, C17.2, C18.2, C19.2, C20.2, C21.1, C22.1, C23.2, C24.1, C25.1, C26.2, C27.2, C28.2, C29.2, C30.2, C31.2, C32.2, C33.2, C34.2, D2.2 (A), D3.A, D4.3 (COM), D5.3 (COM), D6.1, D7.1, D8.3 (COM), D9.3 (COM), D10.3 (COM), IC1.1 (ADJ), IC2.1 (ADJ), IC3.2 (GND), IC3.5 (GND), IC5.11 (VSSA), IC5.15 (VREFN), IC5.31 (VSS), IC5.41 (VSS), IC5.55 (VSS), IC5.72 (VSS), IC5.83 (VSS), IC5.97 (VSS), IC6.1 (GND), IC6.12 (GND1), IC6.25 (GND2), IC6.27 (GND3), IC6.28 (GND4), IC6.29 (GND5), IC7.4 (GND), IC7.PAD, J1.5 (GND), J1.S1, J1.S2, J2.4, J2.5, J3.6 (GND), J4.1, J5.3, J5.5, J5.9, JP2.2, LED1.2 (C), LED4.2 (C), R11.1, R17.2, R18.2, R25.1, R25B.P$1 (1), S1.P$1 (1), S2.P$1 (1)
HSPD_HI: C34.1, D4.1 (C1), IC3.13 (CANH1), J2.6, R1.1, TP1.P$1
HSPD_LO: C32.1, D4.2 (C2), IC3.12 (CANL1), J2.14, SJ1.1, TP2.P$1
MSPD_HI: C30.1, D5.2 (C2), IC3.10 (CANH2), J2.3, R2.2, SJ3.1, SJ3.2, TP3.P$1
MSPD_LO: C31.1, D5.1 (C1), IC3.9 (CANL2), J2.11, SJ2.2, SJ4.1, SJ4.2, TP4.P$1
MULTI_HI: C29.1, J2.1, SJ3.3
MULTI_LO: C33.1, J2.8, SJ4.3
unnamed: R1.2, SJ1.2
unnamed: IC5.40 (P1.26/MC1B/PWM1.6/CAP0.0), R20.1
unnamed: R2.1, SJ2.1
unnamed: IC5.50 (P2.13/!EINT3!/I2STX_SDA), IC7.2 (!EN), TP14.P$1
unnamed: LED1.4 (G), R22.2
unnamed: IC6.21 (PIO5), LED3.C
unnamed: C7.2, C12.1
unnamed: LED3.A, R19.2
unnamed: IC5.38 (P1.24/MCFB2/PWM1.5/MOSI0), R21.1
unnamed: IC5.37 (P1.23/MCFB1/PWM1.4/MISO0), R22.1
unnamed: LED1.3 (B), R21.2
unnamed: LED1.1 (R), R20.2
unnamed: IC7.5 (ISET), R18.1
unnamed: C27.1, IC7.6 (CT)
unnamed: LED4.4 (G), R4.2
unnamed: IC5.32 (P1.18/USB_UP/PWM1.1/CAP1.0), R4.1
unnamed: C25.2, IC5.18 (RTCX2), Q2.1
unnamed: C8.2, C13.1
unnamed: J1.4 (ID), R25.2, R25B.P$2 (2)
unnamed: D7.2, J1.2 (D-), R10.2
unnamed: C1.2, C5.1
unnamed: C1.1, C3.2 (+), D1.C, IC1.3 (IN)
unnamed: C24.2, IC5.16 (RTCX1), Q2.2
unnamed: D6.2, J1.3 (D+), R7.2, R8.1
unnamed: C26.1, IC5.22 (X1), Q3.3 (2)
unnamed: C28.1, IC5.23 (X2), Q3.1
unnamed: LED2.A, Q1.2 (E), R8.2
unnamed: LED2.C, R11.2
unnamed: Q1.1 (B), R3.1, R9.1
unnamed: LED4.3 (B), R6.2
unnamed: LED4.1 (R), R5.2
unnamed: IC5.34 (P1.20/MCFB0/PWM1.2/SCK0), R6.1
unnamed: IC5.35 (P1.21/!MCABORT!/PWM1.3/SSEL0), R5.1
unnamed: IC7.1 (!FLT), TP22.P$1
unnamed: IC7.8 (!PG), TP23.P$1
unnamed: J3.1 (DTR), SJ5.2
unnamed: IC6.5 (RESET), SJ6.2
unnamed: C21.2, C22.2, FB1.1, IC6.11 (VDD)
RTCK: D10.2 (C2), IC5.100 (RTCK), J5.7, R12.2
TCK: D10.1 (C1), IC5.5 (TCK/SWDCLK), J5.4, R17.1
TDI: D9.1 (C1), IC5.2 (TDI), J5.8, R14.2
TDO: D9.2 (C2), IC5.1 (TDO/SWO), J5.6
TMS: D8.2 (C2), IC5.3 (TMS/SWDIO), J5.2, R13.2
TRST: D8.1 (C1), IC5.4 (!TRST), R15.2
USB_CON: IC5.64 (P2.9/USB_CONNECT/RXD2), R9.2, TP16.P$1
USB_D+: IC5.29 (P0.29/USB_D+), R7.1
USB_D-: IC5.30 (P0.30/USB_D-), R10.1
USB_VBUS: C10.1, D2.1 (C), F1.2, IC5.21 (P1.30/VBUS/AD0.4), J1.1 (VBUS)
VOUT: IC7.7 (VOUT), J4.2, TP15.P$1

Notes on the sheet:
Clocks and JTAG
Bluetooth and USB Connections
OBD Connector and Transceiver
Power
LPC1769 I/O Connections
SJ3,SJ4 - Default between TOP and MIDDLE pads
Sparkfun FTDI Basic Pinout
Downstream automotive power, unregulated, up to 5A
Short SJ5 for auto-reset ISP functionality
Short JP2 and reset to enable ISP bootloader
Hold down S2 and reset to enable USB bootloader
SJ1, SJ2 - short to terminate CAN Bus
Short JP1 to supply upstream power to host

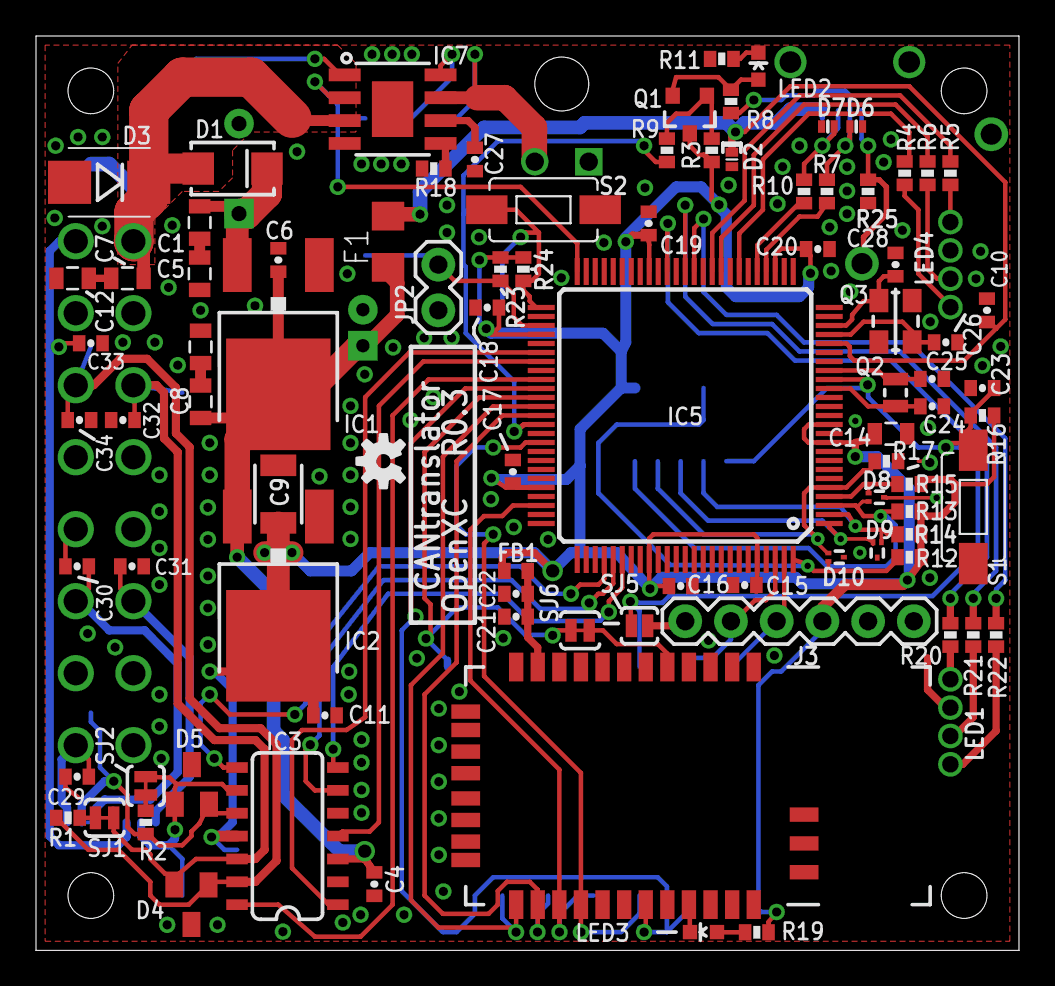
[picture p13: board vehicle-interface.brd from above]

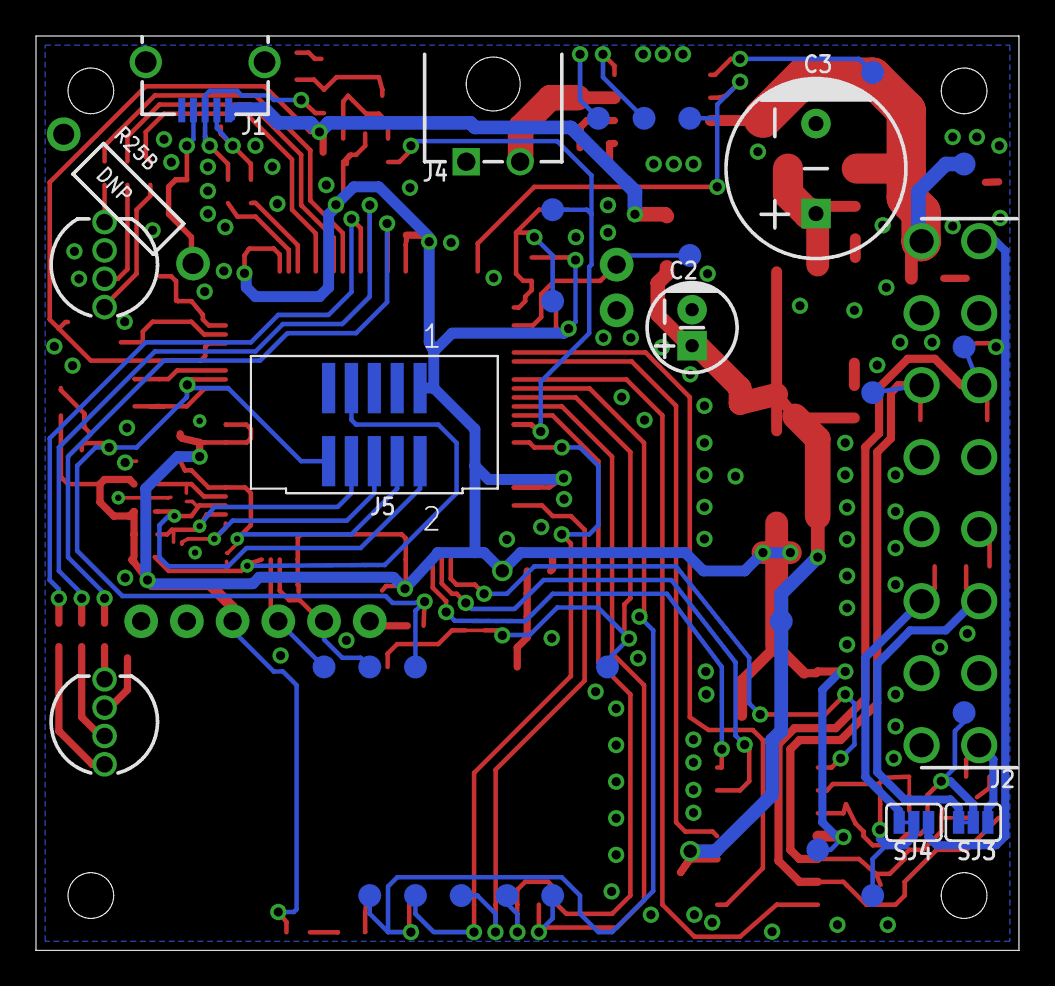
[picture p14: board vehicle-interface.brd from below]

Board: 2 copper layers, 54.6 x 50.8 mm, 125 parts (34 on the bottom side), 76 nets.

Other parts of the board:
DRILEGEND: DRILEGEND
F2: OSHW-LOGO-S
ZDRAW1: A4L-LOC

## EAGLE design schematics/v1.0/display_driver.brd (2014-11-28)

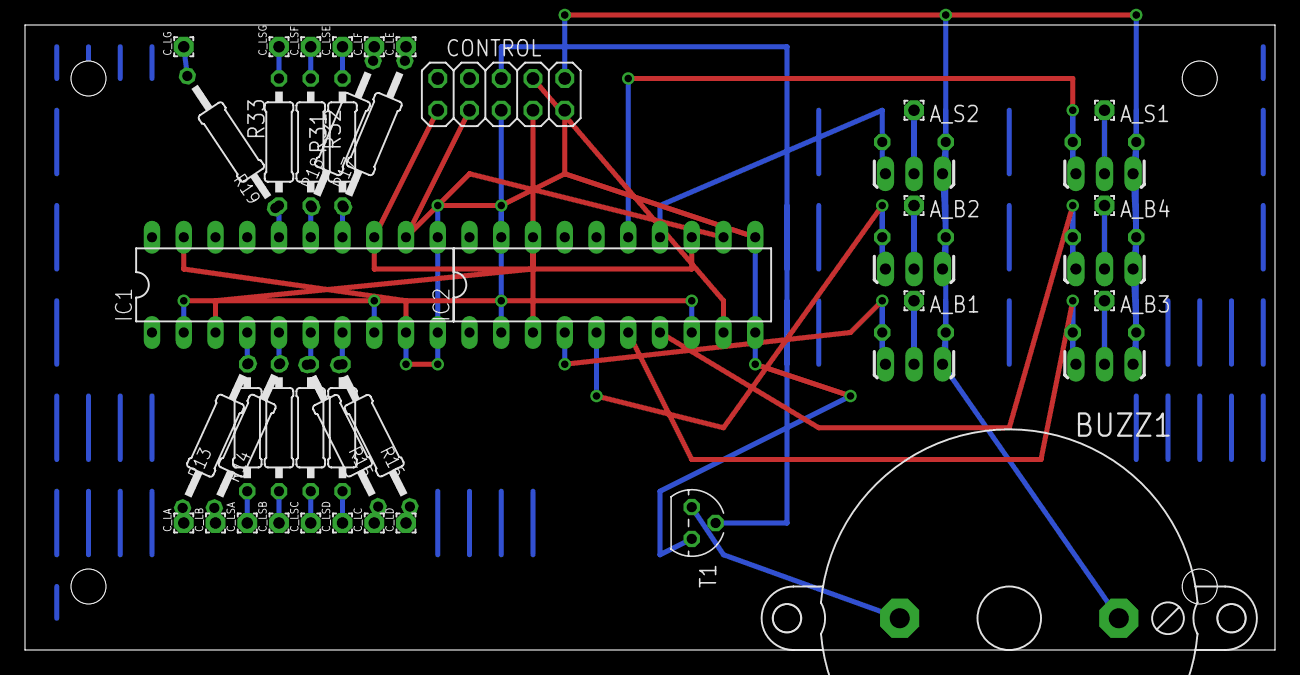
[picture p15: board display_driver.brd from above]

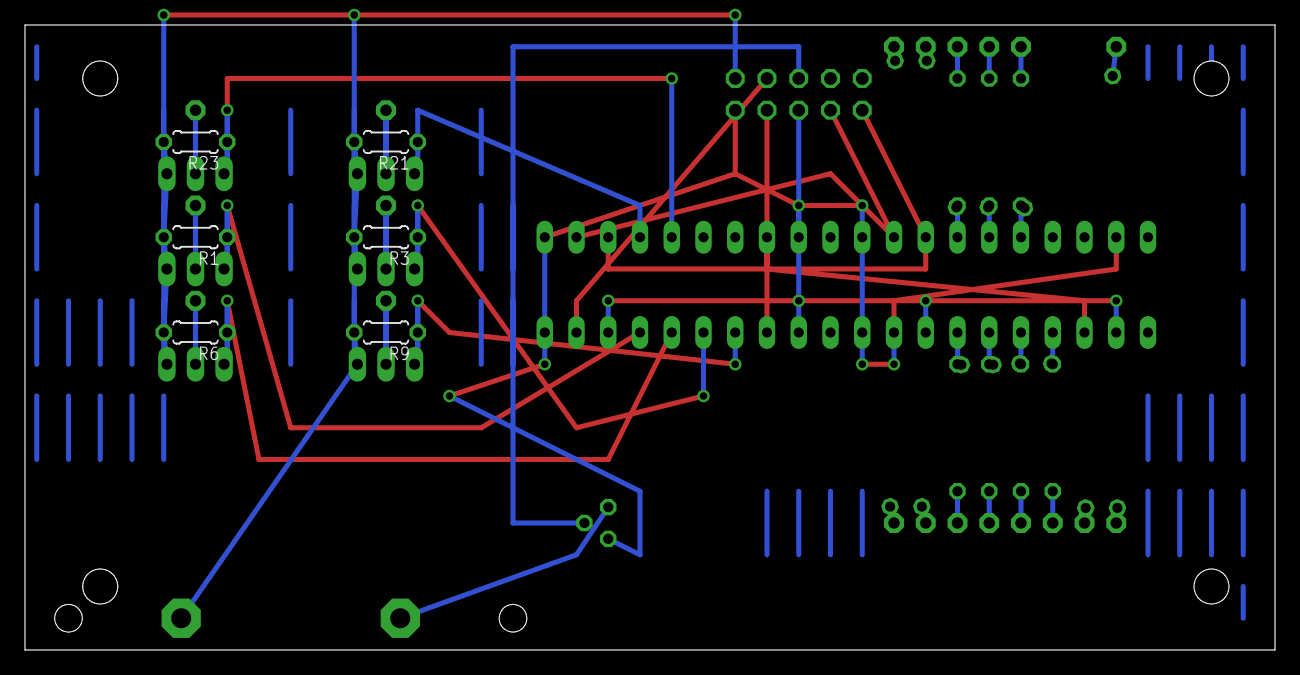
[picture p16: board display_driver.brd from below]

Board: 2 copper layers, 100.0 x 50.0 mm, 51 parts (6 on the bottom side), 43 nets.

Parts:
A_B1, A_B2, A_B3, A_B4: 1,6/0,9
A_S1, A_S2: 1,6/0,9
BUZZ1: F/BC40
CONTROL: JP_1; 2X05
C_LA: 1,6/0,9
C_LB: 1,6/0,9
C_LC: 1,6/0,9
C_LD: 1,6/0,9
C_LE: 1,6/0,9
C_LF: 1,6/0,9
C_LG: 1,6/0,9
C_LSA: 1,6/0,9
C_LSB: 1,6/0,9
C_LSC: 1,6/0,9
C_LSD: 1,6/0,9
C_LSE: 1,6/0,9
C_LSF: 1,6/0,9
C_LSG: 1,6/0,9
IC1, IC2: TPIC6B595N; DIL20
Q1, Q2, Q3, Q4, Q5, Q6: IRFU9024V; TO251AA-V
R1, R3, R6, R9, R21, R23: 22k; 0204/5
R13, R14, R15, R16, R17, R18, R19: 22R; 0207/12
R27, R28, R29, R30, R31, R32, R33: 56R; 0207/10
T1: BC547; TO92

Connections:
+12V: BUZZ1.+, CONTROL.10, Q1.3, Q2.3, Q3.3, Q4.3, Q5.3, Q6.3, R1.2, R3.2, R6.2, R9.2, R21.2, R23.2
BUZZ_CTL: CONTROL.6, T1.2
B_1: IC2.4, Q1.1, R9.1
B_2: IC2.5, Q2.1, R3.1
B_3: IC2.6, Q3.1, R6.1
B_4: IC2.7, Q4.1, R1.1
D0: IC1.4, R13.1, R27.1
D1: IC1.5, R14.1, R28.1
D2: IC1.6, R15.1, R29.1
D3: IC1.7, R16.1, R30.1
D4: IC1.14, R17.1, R31.1
D5: IC1.15, R18.1, R32.1
D6: IC1.16, R19.1, R33.1
G: CONTROL.8, IC2.9
GND: CONTROL.9, IC1.9, IC1.10, IC1.11, IC1.19, IC2.10, IC2.11, IC2.19, T1.1
LS_A: C_LSA.1, R27.2
LS_B: C_LSB.1, R28.2
LS_C: C_LSC.1, R29.2
LS_D: C_LSD.1, R30.2
LS_E: C_LSE.1, R31.2
LS_F: C_LSF.1, R32.2
LS_G: C_LSG.1, R33.2
L_A: C_LA.1, R13.2
L_B: C_LB.1, R14.2
L_C: C_LC.1, R15.2
L_D: C_LD.1, R16.2
L_E: C_LE.1, R17.2
L_F: C_LF.1, R18.2
L_G: C_LG.1, R19.2
unnamed: A_B1.1, Q1.2
unnamed: BUZZ1.-, T1.3
unnamed: A_B2.1, Q2.2
unnamed: A_B3.1, Q3.2
unnamed: A_B4.1, Q4.2
unnamed: IC1.3, IC2.18
unnamed: A_S2.1, Q6.2
unnamed: A_S1.1, Q5.2
RCK: CONTROL.3, IC1.12, IC2.12
SER_IN: CONTROL.7, IC2.3
SRCK: CONTROL.1, IC1.13, IC2.13
S_1: IC2.15, Q5.1, R23.1
S_2: IC2.14, Q6.1, R21.1
VCC: CONTROL.5, IC1.2, IC1.8, IC2.2, IC2.8

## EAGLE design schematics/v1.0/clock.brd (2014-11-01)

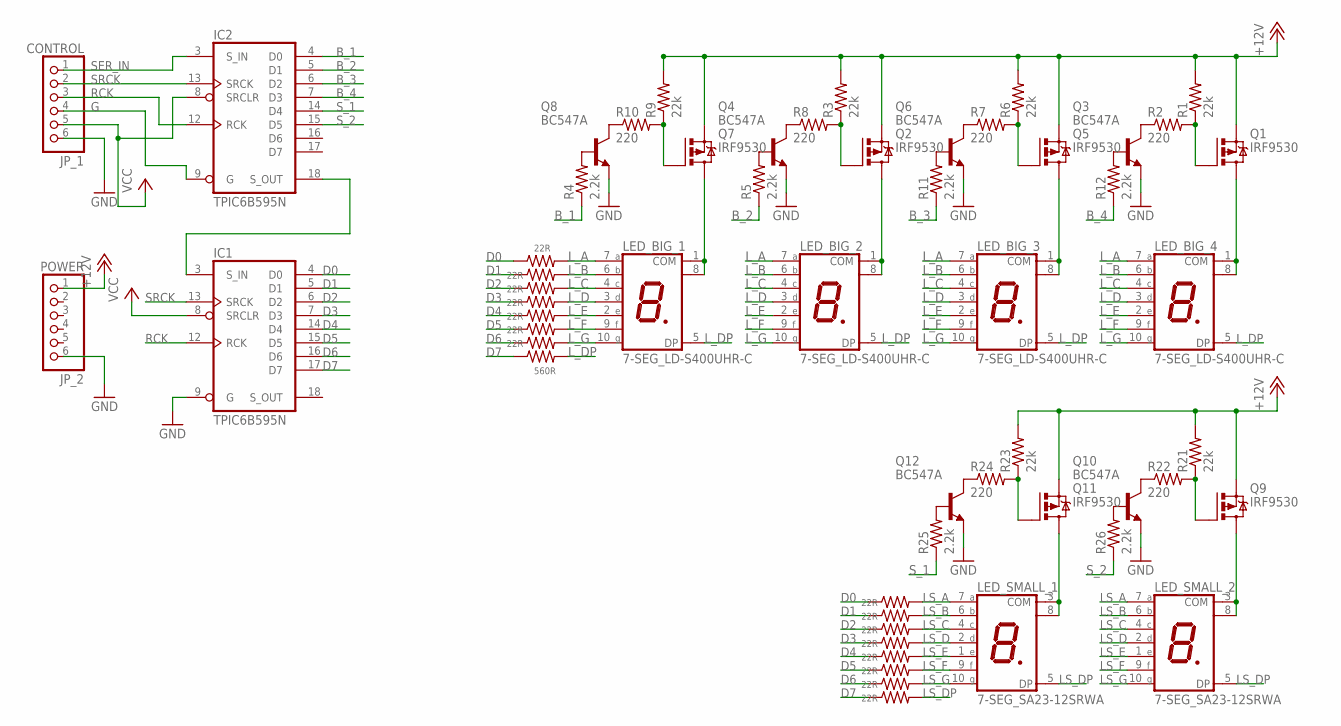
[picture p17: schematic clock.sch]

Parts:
CONTROL: JP_1; 1X06
IC1, IC2: TPIC6B595N; DIL20
LED_BIG_1, LED_BIG_2, LED_BIG_3, LED_BIG_4: 7-SEG_LD-S400UHR-C; LD-S400UHR-C
LED_SMALL_1, LED_SMALL_2: 7-SEG_SA23-12SRWA; SA23-12SRWA
POWER: JP_2; 1X06
Q1, Q2, Q5, Q7, Q9, Q11: IRF9530; TO220BV
Q3, Q4, Q6, Q8, Q10, Q12: BC547A; TO92
R1, R3, R6, R9, R21, R23: 22k; 0207/12
R2, R7, R8, R10, R22, R24: 220; 0207/12
R4, R5, R11, R12, R25, R26: 2.2k; 0207/12
R13, R14, R15, R16, R17, R18, R19, R27, R28, R29, R30, R31, R32, R33, R34: 22R; 0207/12
R20: 560R; 0207/12

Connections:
+12V: POWER.1, Q1.S, Q2.S, Q5.S, Q7.S, Q9.S, Q11.S, R1.2, R3.2, R6.2, R9.2, R21.2, R23.2
B_1: IC2.4 (D0), R4.1
B_2: IC2.5 (D1), R5.1
B_3: IC2.6 (D2), R11.1
B_4: IC2.7 (D3), R12.1
D0: IC1.4 (D0), R13.1, R27.1
D1: IC1.5 (D1), R14.1, R28.1
D2: IC1.6 (D2), R15.1, R29.1
D3: IC1.7 (D3), R16.1, R30.1
D4: IC1.14 (D4), R17.1, R31.1
D5: IC1.15 (D5), R18.1, R32.1
D6: IC1.16 (D6), R19.1, R33.1
D7: IC1.17 (D7), R20.1, R34.1
G: CONTROL.4, IC2.9 (G)
GND: CONTROL.6, IC1.9 (G), IC1.10 (GND), IC1.11 (GND), IC1.19 (GND), IC2.10 (GND), IC2.11 (GND), IC2.19 (GND), POWER.6, Q3.1 (E), Q4.1 (E), Q6.1 (E), Q8.1 (E), Q10.1 (E), Q12.1 (E)
LS_A: LED_SMALL_1.7 (A), LED_SMALL_2.7 (A), R27.2
LS_B: LED_SMALL_1.6 (B), LED_SMALL_2.6 (B), R28.2
LS_C: LED_SMALL_1.4 (C), LED_SMALL_2.4 (C), R29.2
LS_D: LED_SMALL_1.2 (D), LED_SMALL_2.2 (D), R30.2
LS_DP: LED_SMALL_1.5 (DP), LED_SMALL_2.5 (DP), R34.2
LS_E: LED_SMALL_1.1 (E), LED_SMALL_2.1 (E), R31.2
LS_F: LED_SMALL_1.9 (F), LED_SMALL_2.9 (F), R32.2
LS_G: LED_SMALL_1.10 (G), LED_SMALL_2.10 (G), R33.2
L_A: LED_BIG_1.7 (A), LED_BIG_2.7 (A), LED_BIG_3.7 (A), LED_BIG_4.7 (A), R13.2
L_B: LED_BIG_1.6 (B), LED_BIG_2.6 (B), LED_BIG_3.6 (B), LED_BIG_4.6 (B), R14.2
L_C: LED_BIG_1.4 (C), LED_BIG_2.4 (C), LED_BIG_3.4 (C), LED_BIG_4.4 (C), R15.2
L_D: LED_BIG_1.3 (D), LED_BIG_2.3 (D), LED_BIG_3.3 (D), LED_BIG_4.3 (D), R16.2
L_DP: LED_BIG_1.5 (DP), LED_BIG_2.5 (DP), LED_BIG_3.5 (DP), LED_BIG_4.5 (DP), R20.2
L_E: LED_BIG_1.2 (E), LED_BIG_2.2 (E), LED_BIG_3.2 (E), LED_BIG_4.2 (E), R17.2
L_F: LED_BIG_1.9 (F), LED_BIG_2.9 (F), LED_BIG_3.9 (F), LED_BIG_4.9 (F), R18.2
L_G: LED_BIG_1.10 (G), LED_BIG_2.10 (G), LED_BIG_3.10 (G), LED_BIG_4.10 (G), R19.2
unnamed: LED_BIG_4.1 (COM), LED_BIG_4.8 (COM), Q1.D
unnamed: Q1.G, R1.1, R2.2
unnamed: Q3.3 (C), R2.1
unnamed: LED_BIG_3.1 (COM), LED_BIG_3.8 (COM), Q5.D
unnamed: Q5.G, R6.1, R7.2
unnamed: Q6.3 (C), R7.1
unnamed: Q2.G, R3.1, R8.2
unnamed: Q4.3 (C), R8.1
unnamed: LED_BIG_2.1 (COM), LED_BIG_2.8 (COM), Q2.D
unnamed: Q7.G, R9.1, R10.2
unnamed: Q8.3 (C), R10.1
unnamed: LED_BIG_1.1 (COM), LED_BIG_1.8 (COM), Q7.D
unnamed: Q8.2 (B), R4.2
unnamed: Q4.2 (B), R5.2
unnamed: Q6.2 (B), R11.2
unnamed: Q3.2 (B), R12.2
unnamed: IC1.3 (S_IN), IC2.18 (S_OUT)
unnamed: LED_SMALL_2.3 (COM), LED_SMALL_2.8 (COM), Q9.D
unnamed: Q9.G, R21.1, R22.2
unnamed: Q10.3 (C), R22.1
unnamed: Q11.G, R23.1, R24.2
unnamed: Q12.3 (C), R24.1
unnamed: LED_SMALL_1.3 (COM), LED_SMALL_1.8 (COM), Q11.D
unnamed: Q12.2 (B), R25.2
unnamed: Q10.2 (B), R26.2
RCK: CONTROL.3, IC1.12 (RCK), IC2.12 (RCK)
SER_IN: CONTROL.1, IC2.3 (S_IN)
SRCK: CONTROL.2, IC1.13 (SRCK), IC2.13 (SRCK)
S_1: IC2.14 (D4), R25.1
S_2: IC2.15 (D5), R26.1
VCC: CONTROL.5, IC1.2 (VCC), IC1.8 (SRCLR), IC2.2 (VCC), IC2.8 (SRCLR)

Board: 2 copper layers, 56 parts (0 on the bottom side), 62 nets, no tracks yet.

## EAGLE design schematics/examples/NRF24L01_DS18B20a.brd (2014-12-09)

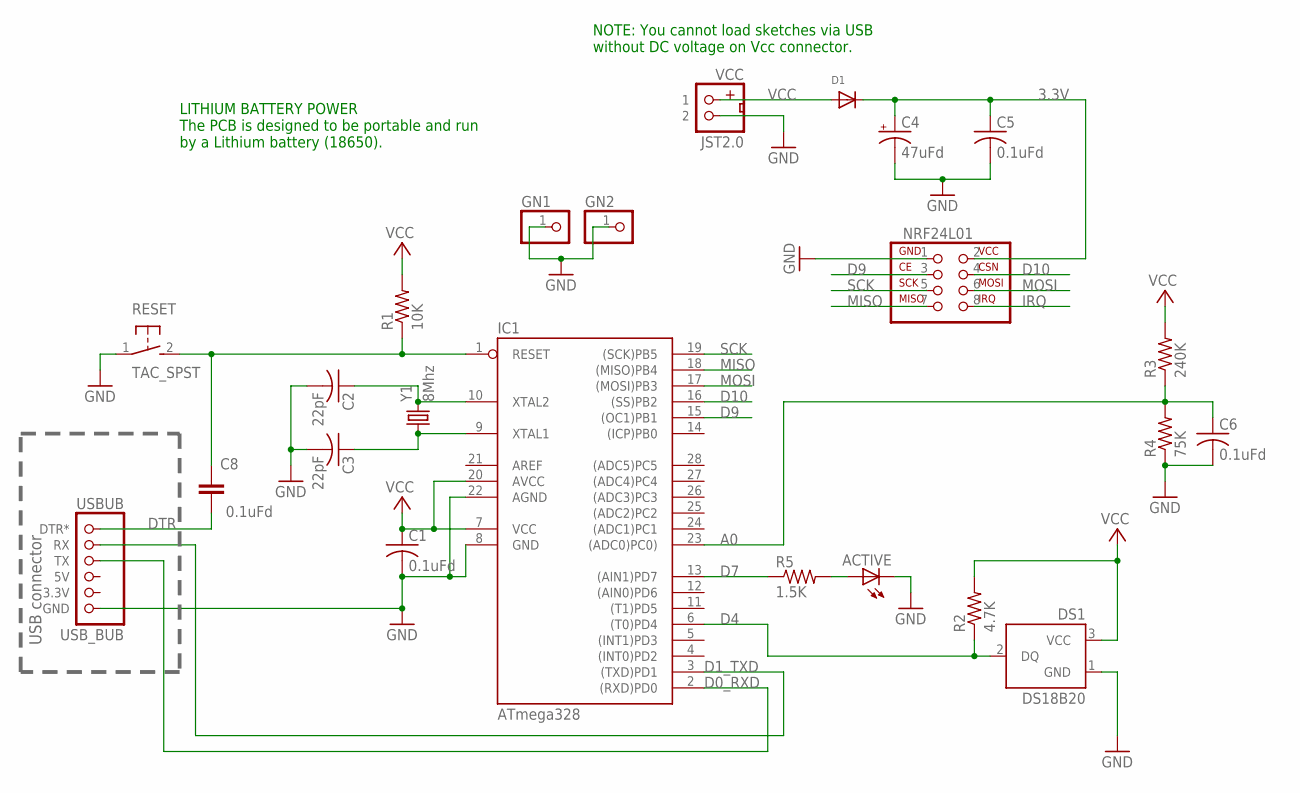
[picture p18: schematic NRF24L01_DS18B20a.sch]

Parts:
ACTIVE: LED3MM
C1, C5, C6: 0.1uFd; C025-025X050
C2, C3: 22pF; C025-025X050
C4: 47uFd; E2,5-6
C8: 0.1uFd; C050-025X075
D1: DIODEDO-1N4148; DO-1N4148
DS1: DS18B20
GN1, GN2: PINHD-1X1; 1X01
IC1: ATmega328; DIL28-3
NRF24L01: NRF24L01+
R1: 10K; 0207/2V
R2: 4.7K; 0207/2V
R3: 240K; 0207/10
R4: 75K; 0207/2V
R5: 1.5K; 0207/2V
RESET: TAC_SPST; TACTILE-SPST
USBUB: USB_BUB
VCC: JST2.0
Y1: 8Mhz; TC38H

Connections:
3.3V: C4.+, C5.1, D1.C, NRF24L01.2
A0: C6.1, IC1.23 ((ADC0)PC0)), R3.1, R4.2
D0_RXD: IC1.2 ((RXD)PD0), USBUB.TX
D1_TXD: IC1.3 ((TXD)PD1), USBUB.RX
D4: DS1.2 (DQ), IC1.6 ((T0)PD4), R2.1
D7: IC1.13 ((AIN1)PD7), R5.1
D9: IC1.15 ((OC1)PB1), NRF24L01.3
D10: IC1.16 ((SS)PB2), NRF24L01.4
DTR: C8.1, USBUB.DTR*
GND: ACTIVE.K (C), C1.2, C2.2, C3.2, C4.-, C5.2, C6.2, DS1.1 (GND), GN1.1, GN2.1, IC1.8 (GND), IC1.22 (AGND), NRF24L01.1, R4.1, RESET.1, USBUB.GND, VCC.2
IRQ: NRF24L01.8
MISO: IC1.18 ((MISO)PB4), NRF24L01.7
MOSI: IC1.17 ((MOSI)PB3), NRF24L01.6
unnamed: ACTIVE.A, R5.2
unnamed: C3.1, IC1.9 (XTAL1), Y1.1
unnamed: C2.1, IC1.10 (XTAL2), Y1.2
RESET: C8.2, IC1.1 (RESET), R1.1, RESET.2
SCK: IC1.19 ((SCK)PB5), NRF24L01.5
VCC: C1.1, D1.A, DS1.3 (VCC), IC1.7 (VCC), IC1.20 (AVCC), R1.2, R2.2, R3.2, VCC.1

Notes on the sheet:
USB connector
LITHIUM BATTERY POWER The PCB is designed to be portable and run by a Lithium battery (18650).
NOTE: You cannot load sketches via USB without DC voltage on Vcc connector.

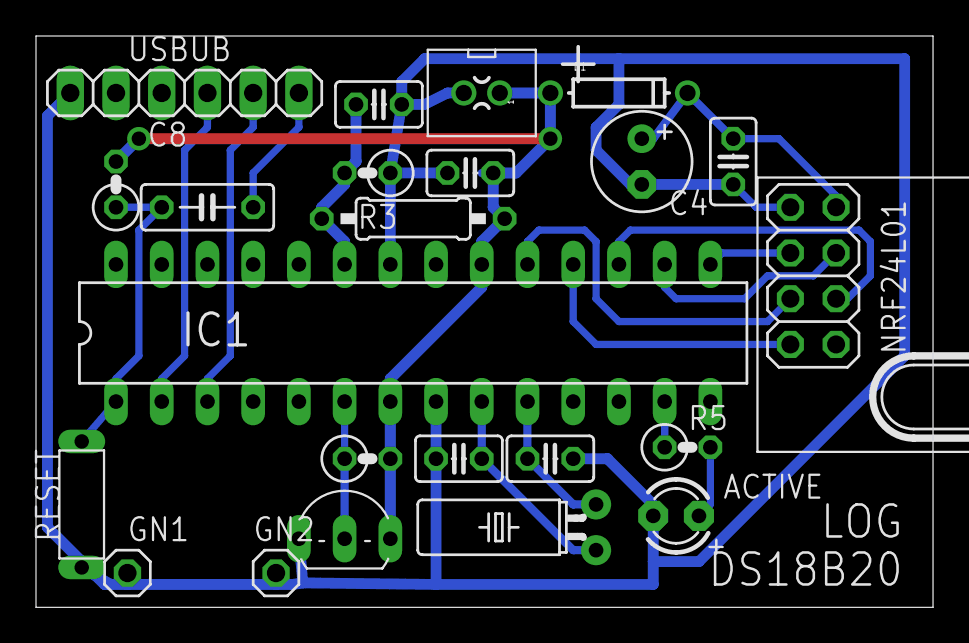
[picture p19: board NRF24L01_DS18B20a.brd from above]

Board: 2 copper layers, 49.8 x 31.7 mm, 23 parts (0 on the bottom side), 18 nets.

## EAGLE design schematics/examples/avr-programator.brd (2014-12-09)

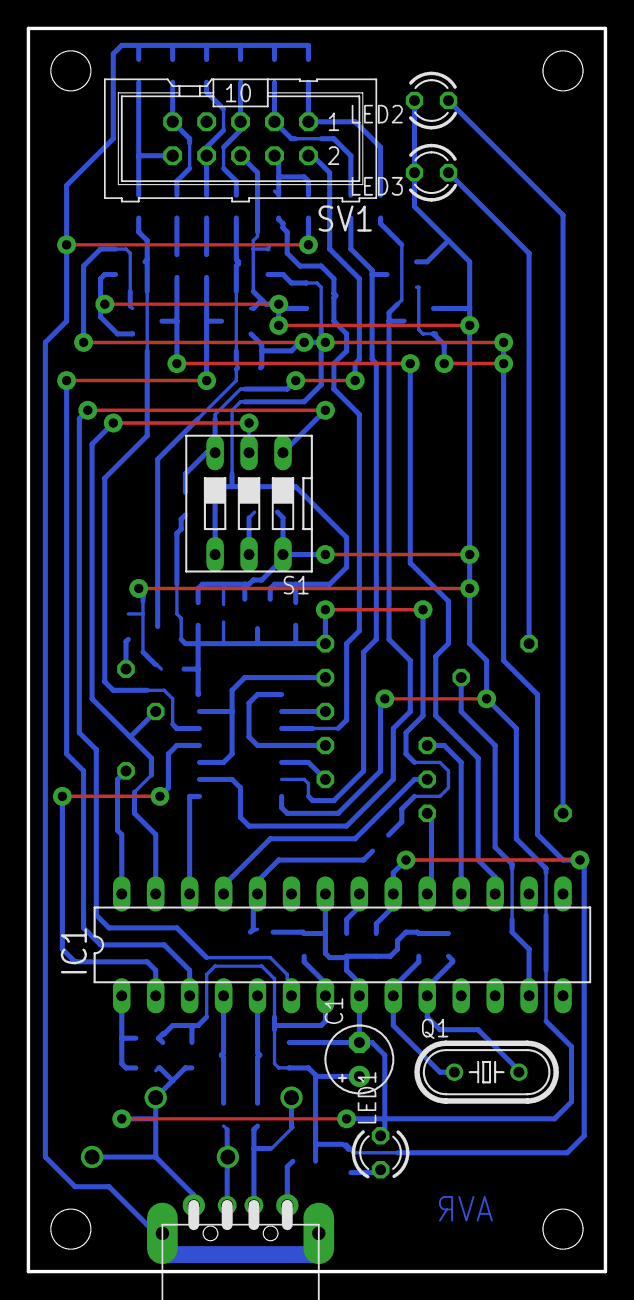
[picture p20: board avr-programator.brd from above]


Board: 2 copper layers, 43.2 x 93.0 mm, 67 parts (58 on the bottom side), 49 nets.

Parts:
C1: 4u7F; E2,5-5
C2, C3, C4, C7, C15, C16, C17: 100nF; C0805
C5, C6: 22pF; C0805
C8, C9, C10, C11, C12, C13, C14: 10pF; C0805
D1, D2: Z3V6; DO41Z10
D3, D4, D5, D6, D7, D8, D9, D10, D11, D12: BAV199; SOT23
D13: Z5V1; SOD523
F1, F2: 0.5A; 0805
IC1: MEGA8-P; DIL28-3
IC2: 74HC126D; SO14
L1, L2, L3, L4, L5, L6, L7: bead; 0805
LED1, LED3: grn; LED3MM
LED2: red; LED3MM
Q1: 12MHZ; HC49/S
R1, R2: 68R; R0805
R3: 2k2; R0805
R4: 1k8; R0805
R5: 1k8; 0207/10
R6: 10k; R0805
R7, R12, R14, R15: 1k; R0805
R8: 10k; 0207/12
R9, R10, R11: 10k; 0207/7
R13: 10k; 0207/10
R16: 33k; R0805
R17: 22k; R0805
R18: 1k8; 0207/15
S1: settings; DS-03
SV1: isp; ML10
T1: BC847; SOT23
X1: usb; MC32603P

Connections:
CLK_S: C14.2, L7.2, SV1.9
D+: D1.C, R2.1, X1.3
D-: D2.C, R1.1, R3.1, X1.2
DRIVER_EN: IC1.18, R10.1
GND: C1.-, C2.2, C3.2, C4.2, C5.2, C6.2, C7.2, C16.2, C17.2, D1.A, D2.A, D3.1, D4.1, D5.1, D6.1, D7.1, D8.1, D9.1, D10.1, D11.1, D12.1, D13.A, IC1.8, IC1.22, IC2.7, LED1.K, LED2.K, LED3.K, R7.2, R17.1, S1.6, SV1.6, T1.2, X1.4
ISP_CLK: D11.3, IC1.17, R15.1
ISP_RESET: IC1.28, R11.1
ISP_SUP_PRESENT: IC1.24, R16.1, R17.2
ISP_TMISO: IC1.26, IC2.8
ISP_TMOSI: IC1.27, R8.1, S1.2
ISP_TSCK: IC1.25, R9.1
unnamed: F1.1, X1.1
unnamed: C4.1, IC1.21
unnamed: C6.1, IC1.10, Q1.2
unnamed: LED1.A, R4.1
unnamed: C5.1, IC1.9, Q1.1
unnamed: LED2.A, R5.1
unnamed: C7.1, IC1.1, R6.1
unnamed: IC1.19, R5.2
unnamed: R7.1, S1.5
unnamed: IC2.2, R8.2
unnamed: IC2.5, R9.2
unnamed: D6.3, IC2.3, L2.1
unnamed: IC2.1, IC2.4, R10.2
unnamed: D5.3, IC2.6, L1.1
unnamed: R11.2, T1.1
unnamed: D7.3, L3.1, R12.2, T1.3
unnamed: D8.3, IC2.9, L4.1
unnamed: D9.3, IC2.12, L5.1
unnamed: IC2.10, IC2.13, R13.2
unnamed: L6.1, R14.2
unnamed: L7.1, R15.2
unnamed: C15.2, C16.1, C17.1, D12.3, D13.C, F2.2, IC2.14, R16.2, R18.2
unnamed: LED3.A, R18.1
REC_EN: IC1.13, R13.1
RESET_S: C10.2, L3.2, SV1.5
RXD: IC1.2, IC2.11
RXD_S: C13.2, L6.2, SV1.8
SHIELD: C8.1, C9.1, C10.1, C11.1, C12.1, C13.1, C14.1, X1.S1, X1.S2
SLOW_SCK: IC1.6, S1.1
TMISO_S: C11.2, L4.2, SV1.1
TMOSI_S: C8.2, L2.2, SV1.4
TSCK_S: C9.2, L1.2, SV1.3
TXD: D10.3, IC1.3, R14.1
TXD_S: C12.2, L5.2, SV1.10
USBM: D3.3, IC1.5, R1.2
USBP: D4.3, IC1.4, R2.2
VCC: C1.+, C2.1, C3.1, C15.1, D3.2, D4.2, D5.2, D6.2, D7.2, D8.2, D9.2, D10.2, D11.2, D12.2, F1.2, IC1.7, IC1.20, R3.2, R4.2, R6.2, R12.1, S1.4
VTG: F2.1, S1.3, SV1.2

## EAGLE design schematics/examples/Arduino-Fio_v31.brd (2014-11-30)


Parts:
C4: 0.1uF; 0603-CAP
C5, C7: 22pF; 0603-CAP
C8, C11: 1uF; 0603-CAP
D1, D5: Yellow; LED-0603
D2: Green; LED-0603
D3: Red; LED-0603
D6: Blue; LED-0603
FRAME1: FRAME-LETTER; CREATIVE_COMMONS
JP1, JP2: M14; 1X14
JP4: AVR_SPI; 2X3
JP5, JP16, JP17: STAND-OFF
JP8, JP9: M01PTH; 1X01
JP10, JP11, JP12, JP13: FIDUCIALUFIDUCIAL; FIDUCIAL-1X2
LOGO1: OSHW-LOGOL; OSHW-LOGO-L
R1, R2, R3, R7, R10: 330; 0603-RES
R6: 10K; 0603-RES
R8: 100; 0603-RES
R11, R12: 22; 0603-RES
R14, R15: 1k; 0603-RES
S3: Reset; TACTILE_SWITCH_SMD
SJ1: SOLDERJUMPERNC; SJ_2S
TP1: RSSI; PAD.03X.05
TP2: ON; PAD.03X.05
U4: XBEE; XBEE-SMD
U5: ATMEGA32U4; QFN-44-NOPAD_1:1
U$1: LOGO-SFENEW; SFE-NEW-WEBLOGO
U$2: REVISION
U$6: FIO_LOGOV2; FUNNEL_LOGO_BOTTOM_V2
X2: USB_MICROB_PLUGCONN-11752; USB-B-MICRO-SMD_V03
Y2: 8MHz; CRYSTAL-SMD-5X3

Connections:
3.3V: JP1.1, JP2.3, JP4.2, R6.2, U4.1 (VDD), U5.14 (VCC), U5.24 (AVCC), U5.34 (VCC), U5.44 (AVCC); also elsewhere on the board
A0: JP2.12, U5.36 (PF7(ADC7))
A1: JP2.11, U5.37 (PF6(ADC6))
A2: JP2.10, U5.38 (PF5(ADC5))
A3: JP2.9, U5.39 (PF4(ADC4))
A4: JP2.8, U5.40 (PF1(ADC1))
A5: JP2.7, U5.41 (PF0(ADC0))
AREF: C4.2, JP2.2, U5.42 (AREF)
ASSOCIATE: R1.2, U4.15 (DIO5)
CHARGE_STAT: U5.32 (PC7); also elsewhere on the board
CTS: JP8.1, U4.12 (CTS)
D2: JP1.3, U5.19 (PD1(SDA))
D3: JP1.4, U5.18 (PD0(SCL))
D4: JP1.5, U5.25 (PD4(ADC8))
D5: JP1.6, U5.31 (PC6)
D6: JP1.7, U5.27 (PD7(ADC10))
D7: JP1.8, U5.1 (PE6)
D8: JP1.9, U5.28 (PB4(ADC11))
D9: JP1.10, U5.29 (PB5(ADC12))
D10: JP1.11, U5.30 (PB6(ADC13))
D11: JP1.12, U5.12 (PB7)
D14: JP1.13, R10.1, U5.8 (PB0(SS))
D+: R11.1, U5.4 (D+)
D-: R12.1, U5.3 (D-)
DTR: SJ1.2
GND: C4.1, C5.2, C7.2, C8.1, C11.1, D1.C, D2.C, D3.C, D5.C, D6.C, JP1.2, JP2.1, JP4.6, R15.1, S3.1, U4.10 (GND), U5.5 (UGND), U5.15 (GND), U5.23 (GND), U5.33 (PE2/!HWB), U5.35 (GND), U5.43 (GND), X2.GND1 (GND); also elsewhere on the board
MISO: JP2.13, JP4.1, U5.11 (PB3(MISO))
MOSI: JP2.14, JP4.4, U5.10 (PB2(MOSI))
unnamed: R3.2, TP2.P$1, U4.13 (DIO9)
unnamed: D1.A, R1.1
unnamed: D2.A, R2.1
unnamed: R2.2, TP1.P$1, U4.6 (RSSI)
unnamed: R11.2, X2.D+1 (D+)
unnamed: D3.A, R3.1
unnamed: R8.2, U4.3 (DIN)
unnamed: SJ1.1, U4.17 (DIO3)
unnamed: D5.A, R7.2
unnamed: C7.1, U5.16 (XTAL2), Y2.1
unnamed: C5.1, U5.17 (XTAL1), Y2.3 (2)
unnamed: D6.A, R10.2
unnamed: R12.2, X2.D-1 (D-)
RST: JP2.6, JP4.5, R6.1, S3.3 (2), U5.13 (!RESET)
RXI: JP2.4, U4.2 (DOUT), U5.20 (PD2(RX))
SCK: JP1.14, JP4.3, U5.9 (PB1(SCK))
SLEEP_RQ: JP9.1, U4.9 (DTR)
TXLED: R7.1, U5.22 (PD5)
TXO: JP2.5, R8.1, U5.21 (PD3(TX))
UCAP: C8.2, U5.6 (UCAP)
USB_VCC: C11.2, U5.2 (UVCC), U5.7 (VBUS), X2.VBUS (VCC); also elsewhere on the board
VBATT: R14.2; also elsewhere on the board
VBATT_LVL: R14.1, R15.2, U5.26 (PD6(ADC9))

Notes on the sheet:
Shigeru Kobayashi
Change to ATmega32U4
Switch to microUSB
New on v3:
Change to 8MHz Xtal
Add battery voltage detect
Add Charge Status to ATmega
Update reset switch
Removed FTDI Connection
Re-arranged and re-named SPI pins
Re-ordered Analog pins
Changed PWM pin designator to ~
Changed VCC to 3.3V
New on v31:
v31
N. Seidle
T. Klopfenstein


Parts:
C1, C13: 10uF; EIA3216
C9: 4.7uF; 0603-CAP
C12: 1uF; 0603-CAP
C14: 0.1uF; 0603-CAP
D4: Yellow; LED-0603
F1: PTCSMD; PTC-1206
FRAME2: FRAME-LETTER; CREATIVE_COMMONS
JP3: M02-JST-2MM-SMT; JST-2-SMD
JP6: External Charge; 1X02
JP7: External Switch; 1X02
JP14: External Power; 1X02
LED1: Red; LED-0603
R5: 2K; 0603-RES
R9: 470; 0603-RES
R13: 330; 0603-RES
S2: Power Switch; AYZ0202
SJ2: USB Power; SJ_2S-TRACE
U1: MCP73831; SOT23-5
U6: MIC5219-3.3; SOT23-5

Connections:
3.3V: C12.1, C13.A (+), C14.2, R13.2, U6.5 (OUT); also elsewhere on the board
CHARGE_STAT: R9.1, U1.1 (STAT); also elsewhere on the board
GND: C1.C (-), C9.2, C12.2, C13.C (-), C14.1, JP3.1, JP6.1, JP14.1, LED1.C, R5.2, U1.2 (VSS), U6.2 (GND); also elsewhere on the board
unnamed: D4.C, R9.2
unnamed: F1.2, JP7.2, S2.3 (S)
unnamed: R5.1, U1.5 (PROG)
unnamed: LED1.A, R13.1
RAW: JP7.1, S2.2, SJ2.1, U6.1 (IN), U6.3 (EN)
USB_VCC: C9.1, D4.A, JP6.2, SJ2.2, U1.4 (VIN); also elsewhere on the board
VBATT: C1.A (+), F1.1, JP3.2, JP14.2, U1.3 (VBAT); also elsewhere on the board

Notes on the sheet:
Max Voltage Input: 16VDC
Max Current Output: 500mA
Cut this jumper if powering the board with more than 5.5V
2K for 500mA charging
10K for 100mA charging



Board: 2 copper layers, 27.9 x 64.8 mm, 66 parts (12 on the bottom side), 55 nets.

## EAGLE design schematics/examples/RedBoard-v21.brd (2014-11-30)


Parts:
AD: M06SMD-STRAIGHT-COMBO; 1X06_SMD_STRAIGHT_COMBO
C1, C2, C4, C8, C10, C12, C14: 0.1uF; 0603-CAP
C3, C6, C15: 10uF; EIA3216
C5: 47uF; PANASONIC_D
C7: 1uF; 0603-CAP
C9, C13: 47pF; 0603-CAP
D1: MBRA140; SMA-DIODE
F1: 500mA; PTC-1206
FRAME2: FRAME-LETTER; CREATIVE_COMMONS
IC3: LM1117; SOT223-ALT1
IOL: M08SMD-COMBO; 1X08_SMD_COMBINED
J1: POWER_JACKOVERPASTE_REDBOARD_0603; POWER_JACK_SMD_OVERPASTE_REDBOARD_0603
J2: ICSP; 2X3_SMT_POSTS
JP1: LOGO-SFENW2; SFE-NEW-WEB
JP2: M10SMD_COMBO; 1X10_SMD_COMBINED
JP3, JP4, JP5, JP6: STAND-OFF
JP7: LOGO-SFESK; SFE-LOGO-FLAME
JP8, JP9: FIDUCIAL1X2; FIDUCIAL-1X2
JP10: M08SMD-COMBO; 1X08_SMD_COMBINED
LED1: Blue; LED-1206-NO_SILK
LED2: Green; LED-1206-NO_SILK
LED3: Red; LED-1206-NO_SILK
LED4: Yellow; LED-1206-NO_SILK
Q1: ZXMP6A13FTA; SOT23-3
Q2: 2N7002PW; SOT323
R1, R2, R6, R7, R8, R9: 1k; 0603-RES
R3, R4, R11, R12: 10k; 0603-RES
R5, R10: 27; 0603-RES
R14: 715; 0603-RES
R15: 240; 0603-RES
S1: RESET; TACTILE_SWITCH_SMD
TP1, TP2, TP3, TP4, TP5, TP6: TP-3x5; PAD.03X.05
U1: FT231XS; SSOP20_L
U2: MIC5205; SOT23-5
U3: ATMEGA328; TQFP32-08
U$13: USB-MINIB-5PIN; USB-MINIB
U$16: OSHW-LOGOS; OSHW-LOGO-S
Y1: 16MHz; RESONATOR-SMD

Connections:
3.3V: C6.A (+), C7.1, C14.1, JP10.5, Q2.1 (G), R11.2, U1.3 (VCCIO), U1.13 (3V3OUT), U1.14 (!RESET), U2.5 (OUT)
5V: C2.2, C3.A (+), C4.1, IC3.2 (OUT), IC3.4 (OUT), J2.2, JP10.4, JP10.7, Q1.2 (S), R2.2, R3.2, R4.2, R6.1, R7.1, R12.2, R15.2, TP1.P$1, U2.1 (IN), U2.3 (EN), U3.4 (VCC), U3.6 (VCC), U3.18 (AVCC)
AD0: AD.1, U3.23 (PC0(ADC0))
AD1: AD.2, U3.24 (PC1(ADC1))
AD2: AD.3, U3.25 (PC2(ADC2))
AD3: AD.4, U3.26 (PC3(ADC3))
AD4/SDA: AD.5, JP2.2A (2), JP2.2B (2), U3.27 (PC4(ADC4/SDA))
AD5/SCL: AD.6, JP2.1A (1), JP2.1B (1), U3.28 (PC5(ADC5/SCL))
AREF: C1.1, JP2.3A (3), JP2.3B (3), U3.20 (AREF)
D+: C9.1, R10.1, U$13.D+
D-: C13.1, R5.1, U$13.D-
DTR: C8.1, Q2.3 (D), R12.1
GND: C1.2, C2.1, C3.C (-), C4.2, C5.-, C6.C (-), C7.2, C9.2, C10.2, C12.2, C13.2, C14.2, C15.C (-), J1.GND (GNDBREAK), J2.6, JP2.4A (4), JP2.4B (4), JP10.2, JP10.3, LED1.C, LED2.C, R14.1, S1.1, S1.2, TP3.P$1, U1.6 (GND), U1.16 (GND), U2.2 (GND), U3.3 (GND), U3.5 (AGND), U3.21 (GND), U$13.GND, U$13.MTN1 (MTN2), U$13.MTN2 (MTN3), U$13.MTN3 (MTN1), U$13.MTN4, Y1.2
INSERT: J1.P$4 (GND), Q1.1 (G), R4.1
IO2: IOL.3, U3.32 (PD2(INT0))
IO3: IOL.4, U3.1 (PD3(INT1))
IO4: IOL.5, U3.2 (PD4(XCK/T0))
IO5: IOL.6, U3.9 (PD5(T1))
IO6: IOL.7, U3.10 (PD6(AIN0))
IO7: IOL.8, U3.11 (PD7(AIN1))
IO8: JP2.10A (10), JP2.10B (10), U3.12 (PB0(ICP))
IO9: JP2.9A (9), JP2.9B (9), U3.13 (PB1(OC1A))
MISO: J2.1, JP2.6A (6), JP2.6B (6), TP4.P$1, U3.16 (PB4(MISO))
MOSI: J2.4, JP2.7A (7), JP2.7B (7), TP2.P$1, U3.15 (PB3(MOSI/OC2))
unnamed: LED1.A, R1.2
unnamed: LED2.A, R2.1
unnamed: U3.7 (PB6(XTAL1/TOSC1)), Y1.1
unnamed: U3.8 (PB7(XTAL2/TOSC2)), Y1.3
unnamed: R5.2, U1.12 (USBDM)
unnamed: R10.2, U1.11 (USBDP)
unnamed: LED3.A, R6.2
unnamed: LED4.A, R7.2
unnamed: Q2.2 (S), R11.1, U1.1 (!DTR)
unnamed: IC3.1 (ADJ), R14.2, R15.1
PWRIN: D1.A, J1.VIN0 (PWR)
RESET: C8.2, J2.5, JP10.6, R3.1, S1.3, S1.4, TP6.P$1, U3.29 (PC6(/RESET))
RX-I: IOL.1, R8.1, U3.30 (PD0(RXD))
RXD: R9.2, U1.4 (RXD)
RXLED: LED4.C, U1.17 (CBUS1)
SCK: J2.3, JP2.5A (5), JP2.5B (5), R1.1, TP5.P$1, U3.17 (PB5(SCK))
SS: JP2.8A (8), JP2.8B (8), U3.14 (PB2(SS/OC1B))
TX-O: IOL.2, R9.1, U3.31 (PD1(TXD))
TXD: R8.2, U1.20 (TXD)
TXLED: LED3.C, U1.10 (CBUS2)
USBVCC: C12.1, C15.A (+), F1.2, Q1.3 (D), U1.15 (VCC)
VIN: C5.+, D1.C, IC3.3 (IN), JP10.1
VUSB: C10.1, F1.1, U$13.VBUS

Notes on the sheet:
Power Supply
ATmega328
FT231XS (USB-to-Serial Converter)
Based on Arduino by: M.Banzi, D.Cuartielles, T.Igoe, G.Martino, D.Mellis
3.3V 150mA Out
Jim Lindblom
v21



Board: 2 copper layers, 68.6 x 54.4 mm, 65 parts (7 on the bottom side), 47 nets.

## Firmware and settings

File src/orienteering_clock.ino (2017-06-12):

#include "hw.h"
#include "test.h"
#include "display_control.h"
#include "buttons.h"
#include "mem.h"

#define VERSION_STR F("1.2.2")

//#define DEBUG_SERIAL

#define BUZZER_SHORT_BEEP  100 // in ms
#define BUZZER_LONG_BEEP   350 // in ms

#define SET_HOLD_MS        3000 // 3 seconds

// raw values read by analog input
#define VOLTAGE_0          670
#define VOLTAGE_100        870

#define BATT_HISTERESIS          1

#define VOLTAGE_SENSE_EVERY_MS        500 // 0.5 second

static int8_t buzzerState = 0;
static int8_t buzzerActive = 1;
static int16_t battPercent = 0;

// difference between "real time" and "millis()" in milliseconds
static long time_offset;

static uint8_t voltage_sense_enabled = 1;
static uint8_t countdown_mode = 0;

static const uint8_t battery_level_percent[]    = {0, 10, 30, 50, 255};
static const uint8_t battery_level_brightness[] = {1, BRIGHTNESS_CRITICAL, BRIGHTNESS_LOW, BRIGHTNESS_WARN, MAX_BRIGHTNESS};

static void voltage_update(long int curr_time) {
#ifdef HAS_VIN_SENSE
    static long int last_volt_sense = 0;
    static uint16_t v_avg = (VOLTAGE_0 + VOLTAGE_100) / 2;
    static uint16_t v_sum_avg = v_avg * 4;
    static uint8_t batt_level = sizeof(battery_level_percent) - 1;

    if (!voltage_sense_enabled) {
        return;
    }

    if ((curr_time - last_volt_sense) < VOLTAGE_SENSE_EVERY_MS) {
        return;
    }

    last_volt_sense = curr_time;

    // simple averaging on last 4 readouts
    uint16_t v = analogRead(VIN_SENSE_PIN - 14);
    v_sum_avg += v - v_avg;
    v_avg = v_sum_avg / 4;
    if (v_avg > VOLTAGE_0) {
        battPercent = (v_avg - VOLTAGE_0) / 2;
    } else {
        battPercent = 0;
    }

    if (battPercent + BATT_HISTERESIS <= battery_level_percent[batt_level - 1]) {
        batt_level -= 1;
    } else if (battPercent - BATT_HISTERESIS > battery_level_percent[batt_level]) {
        batt_level += 1;
    }

    display_setMaxBrightness(battery_level_brightness[batt_level]);

#ifdef DEBUG_SERIAL
    Serial.println(F("BATTERY STATE: "));
    Serial.print(F("\tANALOG 0: "));       Serial.println(v);
    Serial.print(F("\tSUM: "));            Serial.println(v_sum_avg);
    Serial.print(F("\tAVG: "));            Serial.println(v_avg);
    Serial.print(F("\tpercent: "));        Serial.println(battPercent);
    Serial.print(F("\tlevel: "));          Serial.println(batt_level);
#endif
#endif
}


static void check_button_state(long int curr_time) {
    // buttons state machine
    // FUNCTIONS:
    // + UP, DOWN       -> INC/DEC brightness
    // + SET + UP/DOWN  -> change MINUTES
    // + MODE           -> change buzzer state
    // + BATT           -> display battery state
    // + SET + MODE     -> change display mode
    // + SET (hold 3s)  -> reset seconds

    static long int set_pressed_since = 0;

    // SET hold sensing
    if (justpressed[BUTTON_SET_IDX]) {
        if (set_pressed_since == 0) {
            set_pressed_since = curr_time;
        }
    } else if (justreleased[BUTTON_SET_IDX]) {
        set_pressed_since = 0; // will start sensing for SET hold next time
    }

    if (pressed[BUTTON_SET_IDX]) {
        if (justpressed[BUTTON_UP_IDX]) {
            set_pressed_since = -1;// do not sense the SET hold
            time_offset += 60000L; // add one minute
        } else if (justpressed[BUTTON_DOWN_IDX]) {
            set_pressed_since = -1;// do not sense the SET hold
            time_offset -= 60000L; // substract one minute
        } else if (justpressed[BUTTON_MODE_IDX]) {
            set_pressed_since = -1;// do not sense the SET hold
            display_toggleMode();
        } else if (set_pressed_since > 0 && (curr_time - set_pressed_since) > SET_HOLD_MS) {
            // SET hold
            time_offset -= (time_offset + curr_time) % 60000L;   // reset seconds
            set_pressed_since = -1;                              // do not sense the SET hold
        }
    } else {
        if (justpressed[BUTTON_UP_IDX]) {
            display_incBrightness();
        } else if (justpressed[BUTTON_DOWN_IDX]) {
            display_decBrightness();
        } else if (justpressed[BUTTON_MODE_IDX]) {
            buzzerActive = !buzzerActive;
            if (!buzzerActive && buzzerState) { // buzzer is now "playing" - silence it
                buzzerState = 0;
                digitalWrite(BUZZ_CTL, 0);
            }
            display_showBuzzState(buzzerActive);
            mem_set_buzzer_active(buzzerActive);
        }
#ifdef HAS_BUTTON_BATT
        else if (justpressed[BUTTON_BATT_IDX]) {
            display_showBattState(battPercent);
        }
#endif // HAS_BUTTON_BATT
    }
}

void setup() {
    // always initialize serial and output basic info
    Serial.begin(9600);
    Serial.println(F("reset"));
    Serial.print(F("HW REVISION: ")); Serial.println(CURR_HW_REVISION);
    Serial.print(F("VERSION: "));     Serial.println(VERSION_STR);
    mem_setup();
    buzzerActive = mem_was_buzzer_active();

#ifdef TEST_SPI
    test_spi();
#else
    // DISPLAY: setup display control
    display_setup();
#endif
#ifdef TEST_DISPLAY
    for (int i = 0; i < LED_DISPLAYS_CNT; ++i) {
        display_setDP(i, 1);
    }
#endif

    // setup buzzer pin
    pinMode(BUZZ_CTL, OUTPUT);

    buttons_setup();

#ifdef HAS_VIN_SENSE
    pinMode(VIN_SENSE_PIN, INPUT);

#ifdef HAS_BUTTON_BATT
    // overriding VIN sense capability:
    const uint8_t batt_not_pressed = digitalRead(BUTTON_BATT);
    if (!batt_not_pressed) {
        voltage_sense_enabled = 0;
    }
#endif // HAS_BUTTON_BATT
#endif // HAS_VIN_SENSE

    // if SET button is pressed at startup - start in countdown mode
    const uint8_t mode_not_pressed = digitalRead(BUTTON_SET);
    if (mode_not_pressed) {
        // start with "-601 seconds" to display -10:00 at startup
        time_offset = -600999L - millis();
    } else {
        // start with "-3000 seconds"
        countdown_mode = !mode_not_pressed;
        time_offset = -3000000L - millis();
    }

#ifdef DEBUG_SERIAL
    Serial.print(F("Startup took: ")); Serial.println(millis());
#endif
}

/// update displayed time
static void update_time_and_buzzer(long int curr_time) {
    long int curr_secs = curr_time + time_offset;
    long int curr_ms = curr_secs % 1000;
    curr_secs = curr_secs / 1000;
    unsigned int curr_mins = abs(curr_secs / 60);
    unsigned int only_secs = abs(curr_secs % 60);

    if (countdown_mode) {
        // in countdown mode we're displaying centiseconds on smaller display
        display_setValue(abs(curr_secs), abs(curr_ms/10), 0);
    } else {
        display_setValue(curr_mins, only_secs, (curr_secs < 0));
    }

    /// handle buzzer
    if (buzzerActive) {
        if (curr_secs < 0) { // change negative values to proper ones
          only_secs = 59 - only_secs; //only_secs = 59..0
          curr_ms = 999 + curr_ms; //curr_ms = -999... 0
        }
        if (only_secs > 55 || only_secs == 0) {
            const int buzzerOff = (only_secs == 0) ? BUZZER_LONG_BEEP : BUZZER_SHORT_BEEP;
            if (curr_ms < buzzerOff && buzzerState == 0) {
                buzzerState = 1;
                digitalWrite(BUZZ_CTL, 1);
            } else if (curr_ms >= buzzerOff && buzzerState == 1) {
                buzzerState = 0;
                digitalWrite(BUZZ_CTL, 0);
            }
        }
    }
}

#ifdef TEST_DISPLAY
static void test_display(long int curr_time) {
    static long int last_time = 0;
    static int val = 0;

    if (curr_time - last_time > 1000) {
        last_time = curr_time;
        val =  (val + 1) % 10;
        display_setValue(val*1000+val*100+val*10+val, val*10+val, 0);
    }
}
#endif

void loop() {
    long int curr_time = millis();

#ifdef TEST_DISPLAY
    // factory testing: display
    test_display(curr_time);
#else

    // handle button presses
    buttons_update(curr_time);
    check_button_state(curr_time);

    // update time
    update_time_and_buzzer(curr_time);

    // voltage sense
    voltage_update(curr_time);

    // saving stats to EEPROM
    mem_update(curr_time);
#endif
}

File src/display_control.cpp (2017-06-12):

#include "display_control.h"
#include "test.h"
#include "hw.h"

#include <Arduino.h>

// static variables
static uint8_t values[LED_DISPLAYS_CNT];  // values to be send
static uint8_t DPstate[LED_DISPLAYS_CNT]; // dot-point state

static unsigned int currBigValue;
static unsigned int currSmallValue;

static uint8_t currShowMinus;
static uint8_t currBrightness;
static uint8_t currMaxBrightness;
static uint8_t currMode;

// display-related variables
static uint8_t displayDigit;
static uint8_t timerCounter;
static uint8_t timerCounterOnEnd;

// support overriding default output with other text
static const uint8_t* override_big;
static uint8_t override_small[2];

static uint16_t override_times;


// values for each of the digit
static const uint8_t digit_values[] = {
    0x3F, // 0 -> 1111 1100 MSB = 0011 1111 LSB
    0x06, // 1 -> 0110 0000 MSB = 0000 0110 LSB
    0x5B, // 2 -> 1101 1010 MSB = 0101 1011 LSB
    0x4F, // 3 -> 1111 0010 MSB = 0100 1111 LSB
    0x66, // 4 -> 0110 0110 MSB = 0110 0110 LSB
    0x6D, // 5 -> 1011 0110 MSB = 0110 1101 LSB
    0x7D, // 6 -> 1011 1110 MSB = 0111 1101 LSB
    0x07, // 7 -> 1110 0000 MSB = 0000 0111 LSB
    0x7F, // 8 -> 1111 1110 MSB = 0111 1111 LSB
    0x6F, // 9 -> 1111 0110 MSB = 0110 1111 LSB
};

static const uint8_t word_BUZZ[] = {0x7F, 0x3E, 0x5B, 0x5B};
static const uint8_t word_BATT[] = {0x7F, 0x77, 0x31, 0x31};

#define VALUE_MINUS (0x40) // - -> 0100 0000

// for quicker pin switching
#define LATCH_PIN_PORTB (DISPLAY_LATCH_PIN - 8)
#define G_PIN_PORTB     (DISPLAY_G_PIN - 8)

///-------------------///
/// INTERNAL ROUTINES ///
///-------------------///

///////// SPI-related functions ////////////

#ifndef TEST_SPI
static
#endif
void setupSPI() {
    pinMode(DISPLAY_SPI_MOSI_PIN, OUTPUT);
    pinMode(UNUSED_SPI_MISO_PIN, INPUT);
    pinMode(DISPLAY_SPI_SCK_PIN,  OUTPUT);

    // use direct port mappings to omit SPI library
    uint8_t clr;
    SPCR |= ((1<<SPE) | (1<<MSTR));   // enable SPI as master
    SPCR &= ~((1<<SPR1) | (1<<SPR0)); // clear prescaler bits
    clr = SPSR;         // clear SPI status reg
    clr = SPDR;         // clear SPI data reg
    SPSR |= (1<<SPI2X); // set prescaler bits
    (void)clr;          // avoid "unused" warning
    delay(10);
}

// hand-made SPI transfer routine
#ifndef TEST_SPI
static
#endif
uint8_t spiTransfer(uint8_t data) {
    SPDR = data;                    // Start the transmission
    loop_until_bit_is_set(SPSR, SPIF);
    return SPDR;                    // return the received uint8_t, we don't need that
}

///////// TIMER-related functions ////////////

static void setupTimer() {
    // setup timer (2) interrupt
    cli();  // Temporarily stop interrupts

    // See registers in ATmega328 datasheet
    // the interrupt will be each (Clock_freq/(64*TIME_COMPARER))
    TCCR1A = 0;
    TCCR1B = 0;
    TCNT1  = 0;                             // Initialize counter value to 0
    OCR1A = TIMER_COMPARER;                 // Set compare Match Register to 3
    TCCR1B |= (1 << WGM12);                 // Turn on CTC mode
    TCCR1B |= (1 << CS11) | (1 << CS10);    // Set prescaler to 64
    TIMSK1 |= (1 << OCIE1A);                // Enable timer compare interrupt

    sei();  // Continue allowing interrupts
}

static void updateTimings() {
    // we need to have all outputs closed for at least one cycle to close MOSFETs
    // otherwise there will be ghosting on max brightness
    timerCounterOnEnd = BRIGHTNESS_STEP_TICKS * currBrightness - 1;

#ifdef DEBUG_DISPLAY
    Serial.print("TIMINGS: timerCounterOnEnd = ");
    Serial.print(timerCounterOnEnd);
    Serial.print(", timerCounterOffEnd = ");
    Serial.println(ONE_DIGIT_TICKS);
#endif
}

// timed interrupt
static void updateDisplay() {
    if (timerCounter == 0) { // switch to next digit and turn it on.
        do {
            displayDigit = (displayDigit + 1) % LED_DISPLAYS_CNT;
        } while ((override_times == 0) && (values[displayDigit] == 0));

        if (override_times == 0) {
            // display next digit
            spiTransfer(values[displayDigit]);  // segments to display current digits (low-side driver)
            spiTransfer(1 << displayDigit);     // digit numer (high-side driver)
        } else {
            // segments to display current digits (low-side driver)
            if (displayDigit < LED_DISPLAYS_BIG_CNT) {
                spiTransfer(override_big[displayDigit]);
            } else {
                spiTransfer(override_small[displayDigit-LED_DISPLAYS_BIG_CNT]);
            }
            spiTransfer(1 << displayDigit);     // digit numer (high-side driver)
            override_times -= 1;
        }

        // move data from shift-registers to output-registers
        bitClear(PORTB, LATCH_PIN_PORTB);
        bitSet(PORTB, LATCH_PIN_PORTB);

        // enable high-side driver outputs
        bitClear(PORTB, G_PIN_PORTB);
    }

    if (timerCounter == timerCounterOnEnd) {
        // Finished with on-part. Turn off digit, and switch to the off-phase
        // setting G pin high will quickly disable the outputs
        bitSet(PORTB, G_PIN_PORTB);
    }

    // increment the library's counter
    timerCounter = (timerCounter + 1) % ONE_DIGIT_TICKS;
}

// connect updateDisplay to timer(2) interrupt
ISR(TIMER1_COMPA_vect) {
    updateDisplay();
}

///////// TIMER-related functions ////////////

static void computeBigValues() {
    int value = currBigValue;
    int8_t index = LED_DISPLAYS_BIG_CNT - 1;
    uint8_t currDigit;
    int8_t valueEndIdx = -1;

    if (currMode == MODE_HOURS) {
        // change MINUTES to HOURS.MINUTES
        value = (value / 60) * 100 + value % 60;
    }

    // set ALL value registers to clear previous digits and set DPstate
    // use do-while to display at least one '0'
    do {
        currDigit = value % 10;
        value = value / 10;
        values[index] = digit_values[currDigit] | DPstate[index];

        // check if value has ended and mark first free slot
        if (valueEndIdx < 0 && value == 0) {
            valueEndIdx = index - 1;
        } else if (valueEndIdx >= 0) {
            // value has already ended, do not display zeros
            values[index] = DPstate[index];
        }

        index -= 1;
    } while (index >= 0);

    if (currMode == MODE_HOURS) {
        // add leading zeros in HOURS mode
        while (valueEndIdx > 0) {
            values[valueEndIdx] = digit_values[0] | DPstate[valueEndIdx];
            valueEndIdx -= 1;
        }
    }

    if (currShowMinus && (valueEndIdx >= 0)) {
        values[valueEndIdx] = VALUE_MINUS | DPstate[valueEndIdx];
    }

#ifdef DEBUG_DISPLAY
    for (int i = 0; i < LED_DISPLAYS_CNT; ++i) {
        Serial.print("values[");
        Serial.print(i);
        Serial.print("] = ");
        Serial.println(values[i]);
    }
#endif
}
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

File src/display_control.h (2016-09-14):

#ifndef _DISPLAY_CONTROL_H
#define _DISPLAY_CONTROL_H
/* Display control driver for Orieentering Clock.
 *
 * HARDWARE:
 * - 6 common anode 7-segment led displays
 * - 2 chained shift registers connected to SPI port:
 *    - first: high side switch (controlling MOSFETs throuth NPN transistors) (first 6 drains)
 *    - second: low-side switch for CA segments A-G (D0-D6)
 *
 * The update is timer-interrupt driven.
 */

#include <Arduino.h>
#include "test.h"

// enable for debugging
//#define DEBUG_DISPLAY

// configuration
#define LED_DISPLAYS_BIG_CNT    4
#define LED_DISPLAYS_SMALL_CNT  2
#define LED_DISPLAYS_CNT        (LED_DISPLAYS_BIG_CNT + LED_DISPLAYS_SMALL_CNT)

#define MIN_BRIGHTNESS          1
#define MAX_BRIGHTNESS          10

#define DEFAULT_BRIGHTNESS      7

#define BRIGHTNESS_WARN         5
#define BRIGHTNESS_LOW          3
#define BRIGHTNESS_CRITICAL     1

#define ONE_DIGIT_US    2400

// do not change these:
#define CLOCK_HZ        16000000
#define TIMER_PRESCALER (64)
#define TIMER_COMPARER  (15)
#define TIMER_DIVISOR   (TIMER_PRESCALER * TIMER_COMPARER)
#define ONE_TICK_US     (1000000L / (CLOCK_HZ / TIMER_DIVISOR)) // exactly 60us


#define ONE_DIGIT_TICKS (ONE_DIGIT_US / ONE_TICK_US)                // 40 ticks
#define BRIGHTNESS_STEP_TICKS (ONE_DIGIT_TICKS / MAX_BRIGHTNESS)    // 4 ticks

// compute refresh rate
#define REFRESH_RATE (1000000L / (ONE_DIGIT_US * LED_DISPLAYS_CNT)) // about 70 Hz (every digit)


// check if storage class for timerCounter is OK - will not get higher than ONE_DIGIT_TICKS + 1
#if ONE_DIGIT_TICKS > 254
#warning "ONE_DIGIT_TICKS too large, increase storage class for timerCounter"
#endif

// setup SPI and timer interrupts - call at start
void display_setup();
// set value to be displayed. Supports only integer values. Flag to show '-' in big display.
void display_setValue(unsigned int bigValue, unsigned int smallValue, uint8_t showMinus);

#define MODE_MINUTES    0
#define MODE_HOURS      1
void display_setMode(uint8_t mode);
void display_toggleMode();

void display_showBuzzState(int buzzState);
void display_showBattState(int percent);

void display_setBrightness(uint8_t brightness); // set brightness level. valid values: MIN-MAX_BRIGHTNESS
void display_incBrightness(); // decrease brightness level till MIN_BRIGHTNESS
void display_decBrightness(); // increase brightness level till MAX_BRIGHTNESS
void display_setMaxBrightness(uint8_t max_brightness); // set temporary maximum brightness level. valid values: MIN-MAX_BRIGHTNESS

// enable/disable dot point at given LED segment
void display_setDP(uint8_t ledSegment, uint8_t value);

#ifdef TEST_SPI
// SPI routines are externally visible only when 'TEST_SPI' is enabled
void setupSPI();
uint8_t spiTransfer(uint8_t data);
#endif

#endif //_DISPLAY_CONTROL_H

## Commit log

2014-11-01 Orienteering Clock
    hardware arduino project
2014-11-01 Adding EAGLE schematics
    [RBBB-SS-V1.0.brd, RBBB-SS-V1.0.sch, clock.brd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]
2014-11-01 src: change Arduino project name
2014-11-03 src: DisplayControl driver
2014-11-03 schematics: added fritzing schema for Arduino Uno prototype
    [zegar_startowy.fzz]
2014-11-03 src: implementing timer interrupts in DisplayControl
2014-11-03 src: timed interrupt partial implementation
2014-11-04 src: add buttons support, use display G pin
2014-11-17 src: buzzer, button fix, debug code
    [display_control.h, orienteering_clock.ino]
2014-11-18 src: disable buzzer, key autorepeat
    [orienteering_clock.ino]
2014-11-18 src: fix dot-point and buzzer disable
    [display_control.cpp, orienteering_clock.ino]
2014-11-25 schematics: current prototyping status
    Working sample :)
    [display_driver.brd, display_driver.sch]
2014-11-25 schematics: PNG files for easier web-view
2014-11-26 schematics: add correct MOSFET parts, improve redability
    [display_driver.brd, display_driver.sch]
2014-11-28 schematics: clean up, new design rules
    [display_driver.brd, display_driver.sch]
2014-11-30 schematics: remove unneeded files
    [RGBW Controller31.brd, RGBW Controller31.sch, Serial-7-Segment-Shield.brd]
2014-11-30 schematics: add sample CC designs
    [Arduino-Fio_v31.brd, Arduino-Fio_v31.sch, Arduino-Pro-Mini.brd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]
2014-12-01 schematics: add SparkFun libraries
2014-12-09 schematics: more examples
    [NRF24L01_DS18B20a.brd, NRF24L01_DS18B20a.sch, NRF24L01_LCD5110.brd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]
2014-12-09 schematics: preparing v2.0 board
    [orienteering_clock_rev2.sch]
2015-01-11 schematics: think about out-of-PCB connections
    [connection-schema.sch]
2015-01-12 schematics: cosmetic changes
    [orienteering_clock_rev2.sch]
2015-01-15 schematics: layout out-of-PCB connection schema
    [connection-schema.sch]
2015-02-03 schematics: 2.0 schematics done
    add: PDF printout of the 2.0 schematics
    [connection-schema.sch, orienteering_clock_rev2.sch]
2015-02-03 schematics: moved old v1.0 schema to subdirectory
    [clock.brd, clock.sch, display_driver.brd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]
2015-02-04 schematics: add openxc OBDII dongle as an example
    [vehicle-interface.brd, vehicle-interface.sch]
2015-02-08 schematics: first attempt at making a board
    changes:
    - removed BUTTONS connector (we will use the standard one)
    - added net classes
    [orienteering_clock_rev2.brd, orienteering_clock_rev2.sch]
2015-02-18 schematics: improvements
    - better packages for resistors
    - slightly better placement
    - added power_out outlet
    - wider net for VCC
    [orienteering_clock_rev2.brd, orienteering_clock_rev2.sch]
2015-02-22 schematichs: push sam DRU/CAM files for DRC
2015-02-22 schematics: redid connections to comply with various DRC
    [orienteering_clock_rev2.brd, orienteering_clock_rev2.sch]
2015-02-24 schematics: part names smashing for silkscreen
    [orienteering_clock_rev2.brd, orienteering_clock_rev2.sch]
2015-02-25 schematics: lbr: change polulu package print
2015-02-25 schematics: modified POWER packages/schema, texts on top silkscreen
    [orienteering_clock_rev2.brd, orienteering_clock_rev2.sch]
2015-02-25 schematics: changed position of small LED segments
    [orienteering_clock_rev2.brd]
2015-02-26 schematics: added option to use LM7805 as voltage regulator
    [orienteering_clock_rev2.brd, orienteering_clock_rev2.sch]
2015-02-26 schematics: lbr: add darwinia logo to MINE.lbr
2015-02-26 schematics: improve silkscreen
    [orienteering_clock_rev2.brd]
2015-02-26 schematics: finishing touches
    [connection-schema.sch, orienteering_clock_rev2.brd, orienteering_clock_rev2.sch]
2015-02-26 schmetcs: gerber file sent to smart-prototyping
2015-04-16 schematics: update pdf and png outputs
2015-04-19 schematics: fix errors on silkscreen
    [orienteering_clock_rev2.brd, orienteering_clock_rev2.sch]
2015-04-19 src: move button sensing from main file
2015-05-07 schematics: updated voltage sense, resistor values for new display
    [orienteering_clock_rev2.brd, orienteering_clock_rev2.sch]
2015-05-11 src: inverted small displays bug in rev2.0
    [display_control.cpp, hw.h, orienteering_clock.ino]
2015-05-11 schematics: inverted small displays bug, revision 2.1
    [orienteering_clock_rev2.brd, orienteering_clock_rev2.sch]
2015-05-19 schematics: add different assembly variants, small fixes
    [connection-schema.sch, orienteering_clock_rev2.brd, orienteering_clock_rev2.sch]
2015-05-19 src: adding Arduino-Makefile submodule
2015-05-19 schematics: removed eagle.epf as it's platform-dependand
2015-05-20 src: display: rework and simplyfy update routine
    [display_control.cpp, display_control.h]
2015-05-20 src: display battery percentage
2015-05-21 src: more sane voltage sense, code cleanup
2015-05-21 src: Arduino-Makefile: new commits
2015-05-21 src: fixed some bugs
    [display_control.cpp, orienteering_clock.ino]
2015-05-21 subproject: Arduino-Makefile: new commits
2015-05-28 src: rev1: changed buttons order
2015-08-12 docs: some case building hints
2015-08-12 docs: xls helping getting char values for 7 segment display
    [7segmentdesign.xls]
2015-11-27 Arduino-Makefile: upgrade subproject
2015-11-27 src: simple boltage steps and reducing max brightness when battery is depleted
2016-09-10 Arduino-Makefile: update to newest version
2016-09-10 src: add board bootstrapping options
2016-09-14 src: better voltage sense with histeresis
2016-11-21 src: optimize display brightness by skipping empty segments
    [display_control.cpp]
2016-11-21 src: hack for disabling voltage sense
2016-11-24 src: move UART strings to flash
2017-03-17 schematics: add realistic board 2d render
2017-06-11 src: fix coding style
    [display_control.cpp, mem.cpp, orienteering_clock.ino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]
2017-06-11 src: fix hanging when increasing max brightness
    [display_control.cpp]
2017-06-12 src: disable current brightness increase when max brightness increases (causes ugly blinking)

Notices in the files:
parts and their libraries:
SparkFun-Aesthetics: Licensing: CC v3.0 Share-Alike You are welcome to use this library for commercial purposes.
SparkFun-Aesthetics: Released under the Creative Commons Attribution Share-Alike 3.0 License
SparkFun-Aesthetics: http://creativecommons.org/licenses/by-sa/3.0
